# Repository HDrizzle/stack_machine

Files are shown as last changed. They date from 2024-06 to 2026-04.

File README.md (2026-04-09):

# Stack Machine Version 2

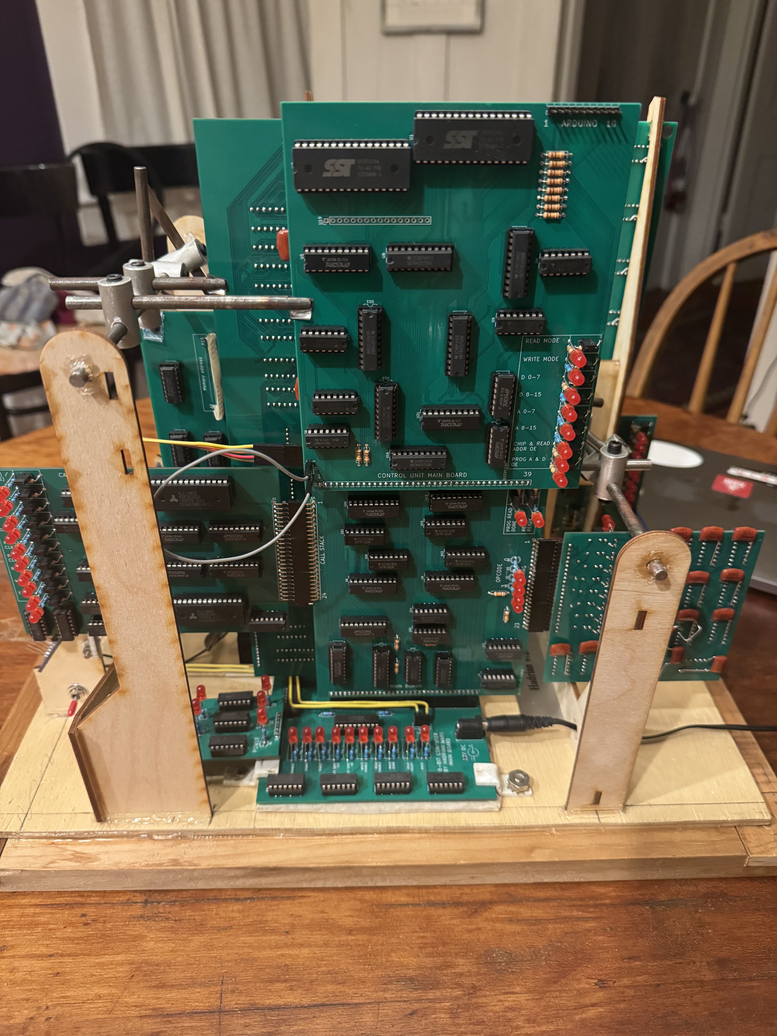
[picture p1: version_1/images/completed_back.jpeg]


Photo of Version 1

## Changes from previous version

* The timing will be completely redone: A single normal clock signal, not the stupid "AB Alternating" I made up for the original.
* The PC will be incremented and a new instruction fetched during any non-flow-control instructions except when the GPRAM is used and the PC is in the same RAM chip (the RAM chips have 15 address lines each) as whatever is being accessed. The bus timing will also be very flexible and will be faster when possible but still slow when the memory is being accessed twice for example.
* Bus read/write addresses are both now 5 bits. The WRITE/MOVE instruction formats will remain the same and the extra bit (MSB to be exact) will be set based on duplicate opcodes for WRITE/MOVE that are otherwise interpreted the same. 1 extra WRITE opcode and 3 extra MOVE opcodes.
* The opcode decoder is actually 3 bits. There will be 4 bits used for extra MOVE/WRITE instructions (see above).
* Interrupts: There will be seperate interrupt GOTO latches that go to a dedicated interrupt handler function. That function should save the state of everything else (including the regular GOTO latches, which is why interrupt GOTO latches are seperate) onto the stack then do whatever depending on the interrupt code.
* GOTO latches can be written to the bus (see above). The goto decider doesn't need to be because it's simple to get its value from an IF-ELSE.
* The control unit will be able to fetch instructions from the GPRAM: Program addresses starting at 2^15 (32,768, halfway through the old flash memory space) will load 2 consecutive bytes (an instruction is 2 bytes) from the GPRAM. The GPRAM address of the first byte (lower byte of the instruction) will be determined by: `(prog_addr - 32,768) * 2`. Since that will only happen at or above 32,768 then the MSB will not be used in the math and will be used to determine whether to read from flash or GPRAM.
* Flash program space is selectable: The flash chips have 17 address lines, while 15 are used (see above about half the program address space being mapped to the GPRAM). This means that the top 2 lines can be connected to jumpers to select between 4 different programs.
* Flash program can be written to from the bus: The programming interface takes 8 data inputs + power and GND. The old interface to plug an Aduino in to program it will still be there of course but it can be selected by a jumper to be either the external pins (to Arduino) or from the bus.
* The stack is 32k instead of 64k so only one memory chip is used, although 32k is still incredibly excessive.

### GPRAM Parallelization

The RAM chips have 15 address lines each so there will be two of them (Lower and Upper Domains). This means that they can be used seperately at the same time, for example fetching the new instruction (If the PC is in the RAM) and also doing GPRAM read/write, as long as these operations are using seperate domains.
Memory users will use either (or both) of the lower or upper RAM domains:

* Program: PC and data read into instruction registers A & B
* Heap R/W: Exactly the same as the original

# Program instructions

Each instruction will be 16 bits and interpreted by the control unit. The first 3 bits (0 - 3) of the instruction will address the below list of operations. The rest of the instruction (bits 4 - 15) may be ignored or used for different things depending on the specific operation.

Here's the current list of the operation codes (opcodes):

0. `MOVE` - Bus usage - The rest of the instruction will be interpreted as follows: bits 8 - 11 address the device which will set the state of the bus (TX) and bits 12 - 15 will address the device to read from it (RX). Bits 4 - 7 are sent to the ALU as it's opcode incase the data is comming from it.
1. `WRITE` - Writes instruction bits 4 - 11 to the bus. Bits 12 - 15 address the device to read from it.
2. `GOTO` - Saves the 2 execution pointer GOTO latches (each of them are 1 byte) to the program counter
3. `GOTO-IF` - Reads the LSB of the value in the goto decider latch and does a GOTO only if it is 1, otherwise does nothing
4. `HALT` - Stops the clock, usefull for debugging
5. `CALL` - Effectively the same as `GOTO` but also pushes the return address (current value of program counter) onto the call stack. Note: The return address can be copied as-is and does not need to be incremented because it will be incremented normally after each `RETURN` instruction when it is used. If bit 4 is 1 this means that this call is calling the interrupt handler using the Interrupt GOTO latches.
6. `RETURN` - The program counter will be set to the return address popped off the top of the call stack. If bit 4 is 1 this means that this return instruction is returning from the interrupt handler function and will allow interrupts again.
7. `CONFIG-INT` - Configure interrupt. Bit 4 enables or disables interrupts. Interrupts are disabled on startup.

The following are treated as either MOVE or WRITE by the sequencer and set the bus TX and RX MSBs. The original MOVE and WRITE have all MSBs = 0.

8. `MOVE` - MSBs TX=1, RX=0
9. `MOVE` - MSBs TX=0, RX=1
10. `MOVE` - MSBs TX=1, RX=1
11. `WRITE` - MSBs RX=1

# Bus

Up to 15 devices can read the bus and 16 write to it.
Devices that can read the bus (RX):

0. `NONE` - Nothing reads this so that bytes can be popped from the stack without them going anywhere.
1. `STACK-PUSH` - Stack controller (Push)
2. `ALU-A` - ALU latch A
3. `ALU-B` - ALU latch B
4. `GOTO-A` - Control unit - Program counter GOTO latch A (first byte)
5. `GOTO-B` - Control unit - Program counter GOTO latch B (second byte)
6. `GOTO-DECIDER` - Control unit - GOTO decider latch (For GOTO-IF)
7. `GPRAM` - GPRAM - Write
8. `GPRAM-INC-ADDR` - GPRAM - Write (++ address)
9. `GPRAM-ADDR-A` - GPRAM - Address bits 0 - 7
10. `GPRAM-ADDR-B` - GPRAM - Address bits 8 - 15
11. `GPIO-WRITE-A` - Writes to GPIO output pins 0 - 7
12. `OFFSET-WRITE` - Replaces value in stack at `ToS - offset`
13. `SET-STACK-OFFSET` - Sets the stack offset byte
14. `ALU-C-IN` - ALU latch for carry and borrow, only LSB is used. Make sure this is always zero when not being used otherwise additions will be wrong.
15. `GPIO-WRITE-B` - Writes to GPIO output pins 8 - 15
16. `INT-GOTO-A` - Interrupt GOTO A
17. `INT-GOTO-B` - Interrupt GOTO B
18. `VECTORS-A` - Vector graphics A input
19. `VECTORS-B` - Vector graphics B input
20. `VECTORS-C` - Vector graphics C input
21. `VECTORS-D` - Vector graphics D input
22. `INT-AND-MAIN-TIMER-ADDRESS` - Bits 0 - 1 address 1 of the 4 interrupt timers. Bit 2 will reset the addressed counter to 0.
23. `INT-TIMER-CONFIG-MAX` - Sets the start value of one of the interrupt timers
24. `INT-TIMER-CONFIG-TIMEBASE-AND-ENABLE` - Configures one of the interrupt timers, see `timer_board.md`
25. `FLASH` - Flash programming interface, same as the arduino connection
26. `RX-26` - Expansion RX 25

...

31. `RX-31` - Expansion RX 31

Devices that can write to the bus (TX):

0. `STACK-POP` - Stack controller (pop)
1. `OFFSET-READ` - Reads value from stack at `ToS - offset`, does not affect the ToS
2. `ALU` - ALU output
3. Control unit instruction bits 4 - 11, used for the `WRITE` instruction
4. `GPRAM` - GPRAM - Read
5. `GPRAM-INC-ADDR` - GPRAM - Read (++ address)
6. `GPRAM-ADDR-A` - GPRAM - Address bits 0 - 7
7. `GPRAM-ADDR-B` - GPRAM - Address bits 8 - 15
8. `GPIO-READ-A` - Reads GPIO input pins 0 - 7
9. `MAIN-TIMER` - 8 bits of the main timer, addressed by `INT-AND-MAIN-TIMER-ADDRESS`
10. `INT-TIMER` - Current value of 1 of the 4 interrupt timers, addressed by `INT-AND-MAIN-TIMER-ADDRESS`
11. `GPIO-READ-B` - Reads GPIO input pins 8 - 15
12. `INT-CODE` - Most recent interrupt code, will be cleared upon read
13. `INT-COUNT` - Number of interrupts in queue, will overflow past 255
14. `GET-STACK-OFFSET` - Retrieves stack offset, needed to save state during interrupt
15. `GET-GOTO-A` - Read GOTO Latch A
16. `GET-GOTO-B` - Read GOTO Latch B
17. `TX-17` - Expansion TX 17

...

31. `TX-31` - Expansion TX 31

# The Stack

The stack will simply be a piece of memory seperate from the pGPRAM and managed by hardware, its has 32k x 8-bit words.

There will be two ways to access the stack:

1. Push and Pop
2. Using the current ToS pointer - stack offset (`OFFSET-WRITE` and `OFFSET-READ`) (does not change ToS). The stack offset will be a 1-byte number set from the bus (`SET-STACK-OFFSET`) and will not affect pushes and pops.

# ALU

The ALU uses 2 8-bit latches for input and has 1 output. The specific operation it does is controlled by 4 bits (2^4 = 16 operations). All operations that result in a boolean output all `0`s except for the result which is the LSB.

0. `ADD` - Add
1. `ADD-C` - Addition carry output (just the LSB will be set), this can be written directly into `ALU-C-IN`
2. `NOT` - Bitwise NOT (latch A)
3. `OR` - Bitwise OR
4. `AND` - Bitwise AND
5. `XNOR` - Bitwise XNOR, whether each pair of bits are equal
6. `SHIFT` - Bitshifts A left by the first 3 bits of B, bits that go off the end DO wrap around.
7. `EQ` - Whether bytes are equal
8. `A` - Contents of A latch
9. `B` - Contents of B latch
10. `EXT-10` - Extension (not implemented)
11. `EXT-11` - Extension (not implemented)
12. `EXT-12` - Extension (not implemented)
13. `EXT-13` - Extension (not implemented)
14. `EXT-14` - Extension (not implemented)
15. `EXT-15` - Extension (not implemented)

# Flow Control

There are four instructions for flow control: `GOTO`, `GOTO-IF`, `CALL`, and `RETURN`.

## GOTO and GOTO-IF

A `GOTO` instruction is used to jump to anywhere in the program. it uses the two 8-bit latches (`GOTO-A` and `GOTO-B`) to set the 16-bit program counter. Due to how the hardware is set up, the PC will be incremented after each goto instruction. This means that the previous address to where the execution should jump to must be used.

`GOTO-IF` is a conditional goto which will do what is described above only if the bit set by `GOTO-DECIDER` from the LSB of the bus is 1, otherwise it does nothing. This is the only instruction that allows the computer to "branch" or "make decisions".

There are macros, `@goto(anchor_name)` and `@goto_if(anchor_name)` that make GOTOs a lot easier.

## Functions and the call stack

Functions in the machine code are defined by `CALL` and `RETURN` instructions. To call a function, make sure the correct pointer to the beginning of the function is stored in the control unit goto A and B latches. Then use the `CALL` instruction which is basically a GOTO but will first put the current program counter value onto the call stack as the return address. The return instruction pops a return address off of the call stack and continues execution.

There is a macro in the assembly language, `@call(function_name)` that makes calling a lot easier.

The call stack is a seperate stack memory containing 256 (1 byte address size) 16-bit words. Each word will be a return address - where to set the program counter during a `RETURN` instruction.

# I/O

There are 16 input and 16 seperate output pins accessible with the `GPIO-READ-A`, `-B` and `GPIO-WRITE-A`, `-B` bus sources/destinations.

## Writing to the display

The display has 32 x 32 LEDs, any given row of 8 pixels are written all at once with one byte. These rows of 8 are addressed by a 7-bit number starting at the top-left and going across for 4 per row (32 / 8 = 4) for each of the 32 rows of the display. The display currently is attached to the gpio-write a and b outputs with gpio-write-a being the address (MSB is ignored) and gpio-write-b being the data. The signal to write the address/data to the display's memory is sent by the hardware when gpio-write-b is written to, meaning the address should be written first and then the data.

# General purpose static-RAM (GPRAM)

This piece of memory does not have any hardware protection like the stack and can be writen to and read from at any location. It will have a 16-bit address by 8-bit word size (65,536 bytes) just like the stack.

Its address can be optionally incremented upon reads/writes and can be directly set from the bus (`GPRAM-ADDR-A` and `GPRAM-ADDR-B`). For the instructions where the address is incremented, that will happen after the read/write.

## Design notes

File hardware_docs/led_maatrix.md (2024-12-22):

# 32 x 32 LED matrix display

Each LED is either on or off

To write to display: Set the 16 bit input so that the first 8 bits address a "byte" of "data" to write to on the display.
Specifically, the bits 0 - 1 address the column and bits 2 - 6 address the row. Bit 7 does nothing.

Each column is 8 bits/pixels wide and is set on a row all at once with bits 8 - 15.

## Memory

2x 32k x 8 SRAM chips in parallel for 32k 16-bit words.
Usage (read): 64 x 16
Usage (write): 128 x 8

## Display loop

For each iteration, 1024/16 = 64 words will be accessed. Each of the 8 drivers will use 1 word per row activation.

### For each row activation (0 - 7)

Every bit in each 16-bit word should be used during the same multiplex iteration.
For each LED driver: Load in the 16-bit word located at address `(floor(driver / 2) * 16) + (driver % 2) + (2 * row_activation)`, this can be implemented easily by concatenating the bits of each term together.
Set the row source from previous row to this one.

## LED drivers

1024 x 20 mA per LED is 20 A (a bit more then 1 A per driver), at 5 volts thats 100 W!! (new screen metric just dropped: 0.1 W/pixel)
Going to use high-side N-channel enhancement MOSFET switches. Update: using the IRF9540.

## Timing

The logic will represent a for loop like so:
```
for row_activation in 0..8 {
	for driver in 0..8 {
		Set memory address
		Get 16-bit word
		for bit_address in 0..16 {
			Clock bit into driver
		}
		Update driver latch
		Load latest written address/data into memory (this isn't necessary but is simpler then having another piece of logic that unly updates on input update)
	}
}
```

Since each variable iterates over a power of two, all 3 counters will just loop over. There is no need to explicitely reset them because that will happen on startup. The bit address counter is driven by the main clock anded with the `Bit address counter enable` signal.

LED driver uptating, representing the pseudo-code inside the `for driver in 0..8` for-loop.
NOTE: The clock pulse that brings the counter from 15 to 0 will be really small since it will be disabled when the counter overflows, although this cannot be represented with the diming diagram, it won't be a race condition.
```
{
  signal: [
    {name: "CLK", wave: "p|.......|"},
    {},
    {name: "Memory read", wave: "l|..h.l..|"},
    {name: "Memory output latch CLK", wave: "l|...hl..|"},
    {name: "Bit address", wave: "2222..2222", data: ["13", "14", "15", "0", "1", "2", "3", "4"]},
    {name: "Counter enable", wave: "h|.l..h..|"},
    {name: "Counter CLK", wave: "p|..l.p..|"},
    {name: "Driver CLK enable", wave: "h|.l.nh..|"},
    {name: "Driver CLK", wave: "n|.l.nn..|"},
    {name: "Driver LE", wave: "l|.hl....|"},
    {},
    {name: "Memory write set data", wave: "l|....h.l|"},
    {name: "Memory write", wave: "l|.....pl|"},
  ]
}
```
I made sure there is a time gap between when the counter rolls over and when `Momery read` goes high because I don't know whether the memory read is edge or level triggered.

The `Memory write set data` signal will control some further combinational logic as follows:
* Low: the read address transparent latch is enabled
* High: The data input address latch is enabled, one of the data input data latches is enabled depending on the LSB of the address.

The `Memory write` should only write to one of the memory chips based on the LSB of the data address, just like the two data latches.

https://pdftobrainrot.org/share/072650e9ef6a43f492dbb5a2f9bec8e8

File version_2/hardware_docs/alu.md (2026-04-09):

# Arithemtic & Logic Unit (ALU)

The ALU will have 3 inputs from the bus:

2. `ALU-A` - ALU latch A
3. `ALU-B` - ALU latch B
14. `ALU-C-IN` - ALU latch for carry and borrow, only LSB is used.

And one output:

2. `ALU` - ALU output

The operation that is performed is controlled through a 4-bit address connected directly from bits 4-7 of the current instruction on the control unit main board.

## Expansion connector

Since only 10 of the 16 addressable instructions are implemented, there is an expansion connector on the ALU board which will allow modding with up to 6 custom functions.

For flexible timing support for the extension, the extension's `TX Ready` and `RX Extend half cycle (to controller)` signals are connected to the corresponding actual bus outputs.

The connections are (1-indexed because pin numbers):

1. A operand 0

...

8. A operand 7
9. B operand 0

...

16. B operand 7
17. C In (1 bit only)
18. Select# 10

...

23. Select# 15
24. Output 0

...

31. Output 7
32. TX Ready, set on rising edge just like actual bus signal
33. A updated, set for 1 cycle on rising edge after input latch clocked on falling edge
34. B updated, set for 1 cycle on rising edge after input latch clocked on falling edge
35. C updated, set for 1 cycle on rising edge after input latch clocked on falling edge
36. CLK
37. RX Extend half cycle, same timing as bus
38. +5V
39. GND

## Timing

There will be 2 main TX timing sequences based on whether the opcode is addressing a built-in function or external function.

### Built-in function TX

`TX Ready` will alway go high immediately since all built-ins are completely combinational. EX Extend (from controller) will be used as per usual to extend the OE to the bus another half cycle.

## External function TX

The function-select# lines will work different, this time not staying low for the `RX Extend` bus input. The `TX Ready` signal to the bus will only go high when the extension's `TX Ready` output goes high. The extension is responsible for extending its OE when the bus `RX Extend (from controller)` goes high.

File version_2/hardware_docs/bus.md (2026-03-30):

# Bus controller

TX and RX addresses are both 5 bits. Both the TX and RX devices have the option to delay TX or RX respectively.

Bus TX ready signals will only last 1 cycle so that recieving logic doesn't have to deal with race conditions.

If the signal `RX extend half cycle` is high then values on the bus should remain valid for another half cycle after "TX Ready" goes low. This is to allow memory writes to happen without sketchy edge cases. This signal is in place to optimize the best possible bus move timing (1 clock cycle, not counting instruction load) but still allow memory writes to happen cleanly. The `RX extend half cycle (to TX device)` signal is delayed by a half cycle to make the timing logic in TX devices simpler.

There may be glitches in the initial move TX signal to bus devices so those signals should always be clocked in to logic on the -edge before anything is done.

When the same device is TXing and also RXing, that device will be responsible for possibly delaying the RX timing chain for 2 clock cycles.

Timing signals
| Signal | Set by | Set clock edge |
| - | - | - |
| Move / TX | Main sequencer | + |
| TX Ready | TX Device | + |
| RX Not Ready | RX Device | + |
| RX extend half cycle (to controller) | RX Device | + |
| RX extend half cycle (to TX device) | controller | - |
| Bus save CLK | Bus controller | - |
| Bus save OE | Bus controller | + |
| Move done | Bus controller | - (half cycle) |

## LEDs

There will be a normal sequencer debug interface on the main board (not sequencer board). There will also be LEDs for each of: Fault, RX Extend to controller, RX not ready, TX ready for each slot. These LEDs will also function as pulldown resistors in the case of empty slots.

## Timing

Plot sources to be pasted into <a href="wavedrom.com/editor.html">Wavedrom</a>.

The data source and destination will have their own sequences

### Without RX extend half cycle

Fastest possible case
```
{
  signal: [
    {name: "CLK", wave: "lhlh"},
	{},
	{name: "Main sequencer -> Move", wave: "lh.l"},
	{},
    {name: "Bus TX", wave: "lh.l"},
	{name: "TX ready", wave: "lh.l"},
	{name: "(actual data valid)", wave: "lh.l"},
	{name: "RX not ready", wave: "l..."},
	{name: "RX extend half cycle (to controller)", wave: "l..."},
	{name: "RX extend half cycle (to TX device)", wave: "l..."},
	{name: "Bus save CLK", wave: "l..."},
	{name: "Bus save OE", wave: "l..."},
	{name: "Move done", wave: "l.hl"}
  ],
  edge: []
}
```

TX not ready, RX Ready
```
{
  signal: [
    {name: "CLK", wave: "lhlhlh"},
	{},
	{name: "Main sequencer -> Move", wave: "lh.l.."},
	{},
    {name: "Bus TX", wave: "lh.l..", node: ".a"},
	{name: "TX ready", wave: "l..h.l", node: "...b"},
	{name: "(actual data valid)", wave: "l..h.l"},
	{name: "RX not ready", wave: "l....."},
	{name: "RX extend half cycle (to controller)", wave: "l....."},
	{name: "RX extend half cycle (to TX device)", wave: "l....."},
	{name: "Bus save CLK", wave: "l....."},
	{name: "Bus save OE", wave: "l....."},
	{name: "Move done", wave: "l...hl"}
  ],
  edge: ["a~>b TX Delay (possibly instant)"]
}
```

TX not ready, RX Not ready
```
{
  signal: [
    {name: "CLK", wave: "lhlhlhlh"},
	{},
	{name: "Main sequencer -> Move", wave: "lh.l...."},
    {},
	{name: "Bus TX", wave: "lh.l....", node: ".a"},
	{name: "TX ready", wave: "l..h.l..", node: "...b"},
	{name: "(actual data valid)", wave: "l..h.h.l"},
	{name: "RX not ready", wave: "l..h.l.."},
	{name: "RX extend half cycle (to controller)", wave: "l......."},
	{name: "RX extend half cycle (to TX device)", wave: "l......."},
	{name: "Bus save CLK", wave: "l...h.l."},
	{name: "Bus save OE", wave: "l....h.l"},
	{name: "Move done", wave: "l.....hl"}
  ],
  edge: ["a~>b TX Delay (possibly instant)"]
}
```

### With RX extend half cycle

Fastest possible case
```
{
  signal: [
    {name: "CLK", wave: "lhlhl"},
	{},
	{name: "Main sequencer -> Move", wave: "lh.l."},
	{},
    {name: "Bus TX", wave: "lh.l."},
	{name: "TX ready", wave: "lh.l."},
	{name: "(actual data valid)", wave: "lh..l"},
	{name: "RX not ready", wave: "l...."},
	{name: "RX extend half cycle (to controller)", wave: "lh.l."},
	{name: "RX extend half cycle (to TX device)", wave: "l.h.l"},
	{name: "Bus save CLK", wave: "l...."},
	{name: "Bus save OE", wave: "l...."},
	{name: "Move done", wave: "l...h"}
  ],
  edge: []
}
```

TX not ready, RX Ready
```
{
  signal: [
    {name: "CLK", wave: "lhlhlhl"},
	{},
	{name: "Main sequencer -> Move", wave: "lh.l..."},
	{},
    {name: "Bus TX", wave: "lh.l...", node: ".a"},
	{name: "TX ready", wave: "l..h.l.", node: "...b"},
	{name: "(actual data valid)", wave: "l..h..l"},
	{name: "RX not ready", wave: "l......"},
	{name: "RX extend half cycle (to controller)", wave: "l..h.l."},
	{name: "RX extend half cycle (to TX device)", wave: "l...h.l"},
	{name: "Bus save CLK", wave: "l......"},
	{name: "Bus save OE", wave: "l......"},
	{name: "Move done", wave: "l.....h"}
  ],
  edge: ["a~>b TX Delay (possibly instant)"]
}
```

TX not ready, RX Not ready
```
{
  signal: [
    {name: "CLK", wave: "lhlhlhlhlh"},
	{},
	{name: "Main sequencer -> Move", wave: "lh.l......"},
    {},
	{name: "Bus TX", wave: "lh.l......", node: ".a"},
	{name: "TX ready", wave: "l..h.l....", node: "...b"},
	{name: "(actual data valid)", wave: "l..h.h...l"},
	{name: "RX not ready", wave: "l..h.l...."},
	{name: "RX extend half cycle (to controller)", wave: "l....h.l.."},
	{name: "RX extend half cycle (to TX device)", wave: "l.....h.l."},
	{name: "Bus save CLK", wave: "l...h...l."},
	{name: "Bus save OE", wave: "l....h...l"},
	{name: "Move done", wave: "l.......hl"}
  ],
  edge: ["a~>b TX Delay (possibly instant)"]
}
```

## List of bus slots

0. Control unit main board
1. Program memory
2. GPRAM Shared memory
3. GPRAM Sequencer & address
4. ALU
5. Stack data/main
6. Interrupt handler data/main
7. Timers
8. Vector digital board
9. I/O Controller (horizontal, to the side)
10. Expansion slot 0
11. Expansion slot 1
12. Expansion slot 2
13. Expansion slot 3, mechanical supports in place to attach LED display from version 1

## TX/RX addresses to physical slots TODO

| Bus slot | TX 0 | TX 1 | TX 2 | TX 3 | RX 0 | RX 1 | RX 2 | RX 3 |
| - | - | - | - | - | - | - | - | - |
| Control unit main board | 3 | 15 | 16 | NA | 4 | 5 | 16 | 17 (5th RX, 6, is GOTO decider) |
| Program memory | NA | NA | NA | NA | 25 | NA | NA | NA |
| GPRAM Shared memory | NA | NA | NA | NA | NA | NA | NA | NA |
| GPRAM Sequencer & address | 4 | 5 | 6 | 7 | 7 | 8 | 9 | 10 |
| ALU | 2 | NA | NA | NA | 2 | 3 | 14 | NA |
| Stack data/main | 0 | 1 | 14 | NA | 1 | 12 | 13 | NA |
| Interrupt handler data/main | 12 | 13 | NA | NA | NA | NA | NA | NA |
| Timers | 9 | 10 | NA | NA | 22 | 23 | 24 | NA |
| Vector digital board | NA | NA | NA | NA | 18 | 19 | 20 | 21 |
| I/O Controller | 8 | 11 | NA | NA | 11 | 15 | NA | NA |

## Expansion slot jumper configuration

There are 4 expansion slots, each with 4 TX and 4 RX connections.

Extra TX addresses: 15, extra RX addresses: 6

TX: 16 x 15, RX: 16 x 6

On tthe bus board there are 2 pairs of 0.1" male pin headers to place jumper cables to connect the expansion slots

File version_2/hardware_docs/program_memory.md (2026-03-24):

# Program memory board

The program emory consists of 2 128k x 8 flash chips in parallel for 16 bit word size. Since the control unit can only address 2^15 flash memory words and there are 2^17 available, there will be 2 jumpers that configure the 2 highest MSBs of both the chips.

## Writing

Just like on Version 1 there will be a 10-pin header to connect an Arduino (or any microcontroller) for programming. There will also be a bus connection (`FLASH`) to set the state of the 8 data input pins. There will be a jumper to select between the external (Arduino) and the Bus programming interfaces.

## Logic (all combinational)

Inputs:

* External/Bus `Write mode enable` input
* Write interface `WE#`
* `Bus -> Write` Jumper
* Instruction read source (0=flash)

Outputs:

* `Read mode` = (!`Write mode`) & (!Read source)
* `Write mode` = `Write mode enable`
* `Chip & read addr OE` = `Read mode`
* `Prog A & D OE` = `Write mode`
* `Write interface select (0=bus, 1=external)` = (External `Write mode enable` input) & !((Bus `Write mode enable` input) & (`Bus -> Write` Jumper))

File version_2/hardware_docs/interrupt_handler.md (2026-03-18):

# Hardware Interrupt Handler

This will be a generic board connected to the bus. Interrupts will be triggered by rising edges, falling edges, timers, and comparators. They can be queued up to as many as 256. Both of the read and write pointers will be incremented AFTER the read/write. When an interrupt is triggered or when the handler returns and there is another one queued up, the normal program instruction will be overridden and the special `CALL` will be run with bit 4 set to 1.

Every interrupt has an 8-bit "code". The first 3 bits address the source of the interrupt, bit 3 is always 0, the last 4 bits vary depending on what the interrupt is. Interrupt sources are as follows:

0. Interrupt timer 0
1. Interrupt timer 1
2. Interrupt timer 2
3. Interrupt timer 3
4. Configurable, +4 bits
5. Configurable, +4 bits
6. Configurable, +4 bits
7. Configurable, +4 bits

The 4 configurable interrupts each correspond to a 5-pin header with the 1st pin being the active-high interrupt signal and the other 4 being the upper 4 bits of the interrupt code. For example 16 buttons could be encoded into the 4 customizable bits with the interrupt pin being triggered by any of them.

## Minimum pulse width (CAUTION)

Usually an extremely short pulse (shorter than 1 clock cycle) will be detected as an interrupt since there are SR latches used, however there is a 1/16 chance of that pulse occuring between when that interrupt is read and when it is reset meaning it will be missed. To gurantee the interrupt is never missed make sure it is longer than 1 clock cycle.

## Edge detection

There will be 8 SR latches to remember the state of an interrupt from the previous sample so if an interrupt input goes high for multiple samples there will only be 1 interrupt triggered at the beginning.

## Interface w/ control unit

There will be a single signal to the control unit timing, `Interrupt` which is read on the +clock edge. It will remain high as long as there is at least 1 interrupt in the queue.

## To bus (TX)

12. `INT-CODE` - Oldest interrupt code, will be cleared upon read
13. `INT-COUNT` - 0 to 255, how many interrupts are in the queue

## Timing

Plot sources to be pasted into <a href="wavedrom.com/editor.html">Wavedrom</a>.

Main sequence (independent of computer's sequence)

Pseudocode

```
Loop:
	CLK interrupt address
	CLK current state
	If current state && !prev state:
		CLK write memory counter, Set memory source to write
		Memory write
		Set memory source to read, Current state reset
	Set prev state
	CLK INT-CODE Pre-latch// This must be on -edge to not coincide with the post-latch CLK from bus read
```

Timing diagram (no interrupt)

```
{
	signal: [
		{name: "CLK", wave: "lhlhlhl"},
	{},
		{name: "Interrupt address CLK", wave: "lh.l.h.", node: ".....b"},
		{name: "Current state CLK", wave: "l.h.l.h"},
		{name: "Current state", wave: "l......"},
		{name: "Prev state", wave: "l......"},
		{name: "Memory source (0=read, 1=write)", wave: "l......"},
		{name: "Write address++", wave: "l......"},
		{name: "Memory write", wave: "l......"},
		{name: "Current state reset", wave: "l..hl.."},
		{name: "INT-CODE Pre-latch CLK & Prev state set", wave: "l...hl.", node: "....a"},
	],
	edge: ["a~>b Begin cycle"]
}
```

Timing diagram (Interrupt)

```
{
	signal: [
		{name: "CLK", wave: "lhlhlhlhl"},
	{},
	{name: "Interrupt address CLK", wave: "lh.l...h.", node: ".......b"},
		{name: "Current state CLK", wave: "l.h.l...h", node: "..c"},
		{name: "Current state", wave: "l.h......"},
		{name: "Prev state", wave: "l.....h.."},
		{name: "Memory source (0=read, 1=write)", wave: "l.h..l..."},
		{name: "Write address++", wave: "l.....hl."},
		{name: "Memory write", wave: "l..hl...."},
		{name: "Current state reset", wave: "l..hl....", node: "....d"},
		{name: "INT-CODE Pre-latch CLK & Prev state set", wave: "l.....hl.", node: "......a"},
	],
	edge: ["a~>b Begin cycle", "c~>d Short interrupt will be missed"]
}
```

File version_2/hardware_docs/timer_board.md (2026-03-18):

# Timer board

The timing board will have its own crystal and a large clock divider, it can also triger interrupts.

The base clock will be a 1 MHz crystal. That clock will be fed into 3 cascaded 12-bit counters which roll over every 68719.476736 seconds.

## Interrupt timers (x4)

Interrupt timers will be 8-bit counters with a configurable max value and time base. When they count past their max value and rollover they may be configured to cause an interrupt. Setting the max value to n will make it rollover at n+1, so setting it to 255 will cause it to rollover normally, TODO: Make sure this is how the simulation works.

The timer reset logic resets the timer immediately when it reaches max+1, so the comparator output is high very briefly. To ensure that the interrupt pulse is not too short for the interrupt handler (see "minimum pulse width" in its readme) it must be extended to greater than 1 clock cycle.

## From bus (RX)

22. `INT-AND-MAIN-TIMER-ADDRESS` - Bits 0 - 1 address 1 of the 4 interrupt timers OR a byte of the main timer. Bit 2 will reset the addressed interrupt timer to 0.
23. `INT-TIMER-CONFIG-MAX` - Sets the max value (will rollover past this, not at it)
24. `INT-TIMER-CONFIG-TIMEBASE-AND-ENABLE` - Bits 0 - 3 address every even-indexed bit of the main 36-bit divider up to bit 30, so 0x0 -> 1 MHz, 0x1 -> 250 KHz and so on. Bit 4 sets whether the timer is allowed to cause interrupts. Bit 5 sets whether the counter is currently counting. Bit 0 in this case is the actual 1 MHz signal.

## To bus (TX)

9. `MAIN-TIMER` - 8-bit section of the 36 bit main timer. Addressed by the `INT-AND-MAIN-TIMER-ADDRESS` (see above). Bits indexed are as follows based on that address: 0 -> 4-11, 1 -> 12-19, 2 -> 20-27, 3 -> 28-35. Bit 0 is actually 500 KHz because its still divided by 2.
10. `INT-TIMER` - reads the current value of any of the 4 interrupt timers, addressing works the same as `MAIN-TIMER` and is controlled by `INT-AND-MAIN-TIMER-ADDRESS`.

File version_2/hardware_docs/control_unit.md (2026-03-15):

# Control unit

https://lucid.app/lucidchart/32ad8e9d-d2d1-47b0-a4b6-105ece57e4e0/edit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

Plot sources to be pasted into <a href="wavedrom.com/editor.html">Wavedrom</a>.

## Startup

1. Started by the `Set` input from the startup controller going high, the sequencer `Start` input will go high for exactly 1 cycle (update on -edge). `Start` will disable the GOTO latches OE, post-adder latch OE, and the call stack OE. Pullup resistors will set the inputs to the pre-adder latch to 0xFFFF so when it is incremented it starts at instruction 0x0000.
2. Clock pre-adder address latch
3. Clock post-adder address latch
3. Begin regular cycle

```
{
  signal: [
	{name: "CLK", wave: "lhlhlh"},
	{},
    {name: "Enable", wave: "lh...."},
    {name: "Start", wave: "l.h.l."},
	{name: "Pre-adder latch CLK", wave: "l.h.l."},
    {name: "Load Instruction", wave: "l..h.l"}
  ],
	edge: ["a~>b Wait for instruction done"]
}
```

## Cycle, PC incrementation may be done in parallel

There will be an SR latch `Instruction done` which will be read on +edge to continue with `Begin instruction sequence` for the next instruction.

Load from FLash
```
{
  signal: [
	{name: "CLK", wave: "lhlhlhl"},
	{},
    {name: "Load Instruction", wave: "lh.l..."},
	{name: "Post-adder latch CLK & OE", wave: "lh.l..."},
	{name: "Flash read (PC MSB=0)", wave: "lh.l..."},
    {name: "Instruction pre-latches CLK", wave: "l.h.l..", node: "..a"},
	{name: "Instruction post-latch CLK", wave: "l..h.l.", node: "...b"},
	{name: "Begin instruction sequence", wave: "l..h.l."},
    {name: "Instruction done", wave: "l.hl2..", data: ["flow-ctrl"]}
  ],
	edge: ["a~>b Wait for instruction done"]
}
```

The `Instruction load possible` signal is combinational from the GPRAM sharing circuit and the PC MSB. If the PC MSB = 0 then it is always 1, otherwise it depends on the PC MSB, the GPRAM MSB, and whether the GPRAM is being used.

If at any time during an instruction load, the `Instruction load possible` signal goes low (only will happen from GPRAM usage, always +edge), then the timing chain must loop back into the waiting loop (`Load Instruction`) for it to go high again.

Load from RAM (non delayed)
```
{
  signal: [
	{name: "CLK", wave: "lhlhlhlh"},
	{},
    {name: "Load Instruction", wave: "lh.l...."},
	{name: "Post-adder latch CLK & OE", wave: "lh...l.."},
	{name: "RAM read (PC MSB=1)", wave: "lh...l.."},
    {name: "Instruction load possible (read on -edge)", wave: "xh......"},
	{name: "RAM LSB", wave: "l..h.l.."},
	{name: "Instruction pre-latch A CLK", wave: "l.h.l..."},
	{name: "Instruction pre-latch B CLK", wave: "l...h.l.", node: "....a"},
	{name: "Instruction post-latch CLK", wave: "l....h.l", node: ".....b"},
	{name: "Begin instruction sequence", wave: "l....h.l"},
    {name: "Instruction done", wave: "l...hl2.", data: ["flow-ctrl"]}
  ],
	edge: ["a~>b Wait for instruction done"]
}
```

Load from RAM, start delayed
```
{
  signal: [
	{name: "CLK", wave: "lhlhlhlhlh"},
	{},
    {name: "Load Instruction", wave: "lh.l......"},
	{name: "Post-adder latch CLK & OE", wave: "lh.....l.."},
	{name: "RAM read (PC MSB=1)", wave: "lh.....l.."},
    {name: "Instruction load possible (read on -edge)", wave: "l..h......"},
	{name: "RAM LSB", wave: "l....h.l.."},
	{name: "Instruction pre-latch A CLK", wave: "l...h.l..."},
	{name: "Instruction pre-latch B CLK", wave: "l.....h.l.", node: "......a"},
	{name: "Instruction post-latch CLK", wave: "l......h.l", node: ".......b"},
	{name: "Begin instruction sequence", wave: "l......h.l"},
    {name: "Instruction done", wave: "l.....hl2.", data: ["flow-ctrl"]}
  ],
	edge: ["a~>b Wait for instruction done"]
}
```

## Interrupts

The signal `Interrupt` from the interrupt handler is read on the positive edge and used to determine whether `Instruction post-latch OE` is set. The instruction data bus has pull up/down resistors to hardcode the default value to the interrupt call instruction (0x0015) so when the `Instruction post-latch OE` is low then the interrupt handler will be called.

The interrupt call can only happen when `Interrupt in-progress` is low and `Interrupt enabled` is high. `Interrupt enabled` is an SR latch which is set by:

 * The `CALL` (disable) and `RETURN` (enable) instructions if bit 4 is high (interrupts are automatically disabled when in the interrupt handler or any function calls within it)
 * Disabled on startup
 * The `CONFIG-INT` instruction will enable or disable interrupts. This should not be used inside the interrupt handler except in some kind of weird use case I can't think of.

```
{
  signal: [
	{name: "CLK", wave: "lhlhlhl"},
	{},
    {name: "Load Instruction", wave: "lh.l..."},
	{name: "Post-adder latch CLK & OE", wave: "lh.l..."},
	{name: "Flash read (PC MSB=0)", wave: "lh.l..."},
    {name: "Instruction pre-latches CLK", wave: "l.h.l..", node: "..a"},
	{name: "Instruction post-latch CLK", wave: "l..h.l.", node: "...b"},
	{name: "Instruction post-latch OE", wave: "h..l.h."},
	{name: "Interrupt (latched on +edge)", wave: "x.h...."},
	{name: "Interrupt in-progress", wave: "l...h.."},
	{name: "Begin instruction sequence", wave: "l..h.l."},
    {name: "Instruction done", wave: "l.hl2..", data: ["flow-ctrl"]}
  ],
	edge: ["a~>b Wait for instruction done"]
}
```

## Non-control-flow parallel PC++

```
{
  signal: [
	{name: "CLK", wave: "lhlhlh"},
	{},
	{name: "Begin instruction sequence (non-flow-ctrl)", wave: "lh.l.."},
	{name: "Post-adder latch OE", wave: "lh.l.."},
	{name: "Pre-adder latch CLK", wave: "l.h.l."},
    {name: "Load Instruction", wave: "l..h.l"}
  ],
	edge: []
}
```

## Instruction sequences

NOTE: Even flow-control instructions must set "Instruction Done" high again so that the "Load instruction" sequence will continue to load the new instruction w/o being deadlocked.

### MOVE & WRITE

Refer to "bus.md" for move timing

Fastest possible case
```
{
  signal: [
    {name: "CLK", wave: "lhlhl"},
	{},
	{name: "Begin instruction sequence (MOVE/WRITE)", wave: "lh.l."},
	{},
    {name: "Bus move", wave: "lh.l.", node: ".a"},
    {name: "Move done", wave: "l...h", node: "....b"},
	{name: "Instruction done", wave: "l...h"}
  ],
  edge: ["a~>b Move delay"]
}
```

### GOTO (flow-control)

```
{
  signal: [
    {name: "CLK", wave: "lhlhl"},
	{},
	{name: "Begin instruction sequence (GOTO)", wave: "lh.l."},
	{},
	{name: "GOTO latches OE", wave: "lh.l."},
	{name: "Pre-adder latch CLK", wave: "l.h.l"},
    {name: "Load Instruction", wave: "l..h."}
  ],
  edge: []
}
```

### GOTO-IF (flow-control)

```
{
  signal: [
    {name: "CLK", wave: "lhlhl"},
	{},
	{name: "Begin instruction sequence (GOTO-IF)", wave: "lh.l."},
	{},
	{name: "GOTO latches OE", wave: "l2.l.", data: ["DECIDER"]},
	{name: "Post-adder latch OE", wave: "l2.l.", data: ["!DECIDER"]},
	{name: "Pre-adder latch CLK", wave: "l.h.l"},
    {name: "Load Instruction", wave: "l..h."}
  ],
  edge: []
}
```

### HALT

```
{
  signal: [
    {name: "CLK", wave: "lhlh"},
	{},
	{name: "Begin instruction sequence (HALT)", wave: "lh.l"},
	{name: "Instruction done", wave: "l.h."}
  ],
  edge: []
}
```

### CALL (flow-control)

```
{
  signal: [
    {name: "CLK", wave: "lhlhlhlhl"},
	{},
	{name: "Begin instruction sequence (CALL)", wave: "lh.l....."},
	{},
	{name: "Call stack - Push", wave: "lh.l....."},
    {name: "Interrupt in-progress", wave: "l.2......", data: ["Bit 4"]},
	{name: "Post-adder latch OE", wave: "l.h..l..."},
	{name: "GOTO latches OE", wave: "l....h.l."},
	{name: "Pre-adder latch CLK", wave: "l.....h.l"},
    {name: "Load Instruction", wave: "l......h."}
  ],
  edge: []
}
```

### RETURN (flow-control)

There is a signal `Instruction++` that should always remain high except in the case of returning from an interrupt so that the interrupted instruction can still be run.

```
{
  signal: [
    {name: "CLK", wave: "lhlhl"},
	{},
	{name: "Begin instruction sequence (RETURN)", wave: "lh.l."},
	{},
	{name: "Call stack - Pop & OE", wave: "lh.l."},
    {name: "Interrupt in-progress", wave: "h.2..", data:["!Bit 4"]},
	{name: "Pre-adder latch CLK", wave: "l.h.l"},
    {name: "Load Instruction", wave: "l..h."},
	{name: "Instruction++", wave: "h.2.h", data:["!Bit 4"]}
  ],
  edge: []
}
```

### CONFIG-INT

```
{
  signal: [
    {name: "CLK", wave: "lhlhl"},
	{},
	{name: "Begin instruction sequence (CONFIG-INT)", wave: "lh.l."},
	{},
	{name: "Interrupt enabled S / R", wave: "l.h.l"},
	{name: "Instruction done", wave: "l.h.."}
  ],
  edge: []
}
```

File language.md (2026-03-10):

# Language

The assembly language closely reflects the actual instructions that it will be converted into. Instructions consist of tokens which can be assembly words (defined in `assembler_config/config.json`) and literal values such as `0x42` or `0b0101`. Instructions and macros are seperated by simicolons (`;`) and all whitespace is ignored except for spaces between instruction tokens. Anything after `#` on a line is treated as a comment.

## Macros

Macros are a way to simplify common parts of the program and to make calling functions easier. A macro consists of a name starting with `@` which is made out of identifier characters followed by parenthesis (`()`) with comma-seperated arguments inside them.

### Anchors

Anchors mark a place in a program that may be `call`ed to `goto`ed to, for example:

```
@anchor(function_name)
```

marks the beginning of a function. An anchor can also mean other things such as the beginning of a loop or the end of an if-statement. To go to an achor, use:

```
@call(function_name)
```

which will be expanded to three instructions: `write 0xXX goto-a`, `write 0xXX goto-b`, `call` where it will write the correct address to the GOTO A & B latches. `@goto(_)` and `goto_if(_)` work in the exact same way.

For version 2: `@set_interrupt(_)` will use the given anchor name to setup the interrupt goto latches.

### Write string

Another macro is `@write_string("Hello world")` which will write each character of the given string (in ASCII) to the GPRAM starting at wherever the address is currently set to.

### Get anchor address

Sometimes it is necessary to access the address of an achor without using any flow control macros. This is why there is the `@push_anchor_address(anchor_name)` macro. It will push two bytes onto the stack, starting with address bits 0 - 7 then 8 - 15.

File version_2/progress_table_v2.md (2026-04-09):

# Progress table (for version 2)

| PCB | Timing diagram(s) completed | Built in RustyLogic | Gates numbered | KiCad Schematic verified | Parts list updated | KiCad PCB | PCB built/aquired | Assembled | Tested |
| - | - | - | - | - | - | - | - | - | - |
| Main sequencer | Done | Done | Done | Done | TODO | TODO | TODO | TODO | TODO |
| Call stack | Done | Done | Sequencer only | Done | TODO | TODO | TODO | TODO | TODO |
| Prog memory module | Not needed | Not needed | Not needed | Done | TODO | TODO | TODO | TODO | TODO |
| Ctrl unit main board | Not needed | In toplevel | Done | Done | TODO | TODO | TODO | TODO | TODO |
| Bus Sequencer | Done | Done | Done | Done | TODO | TODO | TODO | TODO | TODO |
| Bus (Motherboard) | Not needed | In toplevel | Not needed | Done | TODO | TODO | TODO | TODO | TODO |
| Start pulse generator | Not needed | Done | Done | Done | TODO | TODO | TODO | TODO | TODO |
| ALU | Not needed | Done | Bus timing only | Done | TODO | TODO | TODO | TODO | TODO |
| Stack controller data/main | Not needed | Done | Not needed | Done | TODO | TODO | TODO | TODO | TODO |
| Stack controller sequencer | Done | Done | Done | TODO | TODO | TODO | TODO | TODO | TODO |
| GPRAM sequencer & address | Done | Done | Sequencer only | TODO | TODO | TODO | TODO | TODO | TODO |
| GPRAM Shared memory | Not needed | Done | Done | TODO | TODO | TODO | TODO | TODO | TODO |
| I/O controller | Done | Done | Sequencer only | TODO | TODO | TODO | TODO | TODO | TODO |
| Vector digital board | Done | Done | Done | TODO | TODO | TODO | TODO | TODO | TODO |
| Timers | Not needed | Done | Done | TODO | TODO | TODO | TODO | TODO | TODO |
| Interrupt handler data/main | Not needed | Done | Done | TODO | TODO | TODO | TODO | TODO | TODO |
| Interrupt sequencer | Done | Done | Done | TODO | TODO | TODO | TODO | TODO | TODO |
| CLK / Control panel | Not needed | Not needed | Not needed | TODO | TODO | TODO | TODO | TODO | TODO |
| Global state LED board | Not needed | Not needed | Not needed | TODO | TODO | TODO | TODO | TODO | TODO |

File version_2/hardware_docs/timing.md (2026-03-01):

# All Timing diagrams go here

The shortest possible cycle is 2 clock cycles.

## Memory read delays

For flash whichever is highest of:
* TCE (chip enable) = 70 ns
* TOE (output enable) = 35 ns
* TOH (hold from address change), maximum unspecified

For RAM whichever is highest of:
* TACE (chip enable) = 55 ns
* TOE (output enable) = 30 ns
* TAA (hold from address change) = 55 ns

## RAM Write delay

* TDW (data valid before write) = 25 ns
* TAW - TDW (address set before write) = 50 ns - 25 ns = 25 ns

Conclusion: These times are comparable to other logic devices so no extra clock cycles needed.

Paste into https://wavedrom.com/editor.html

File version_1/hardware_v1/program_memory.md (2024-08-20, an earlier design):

# Program memory

The program memory board will use 2 <a href="https://ww1.microchip.com/downloads/en/DeviceDoc/20005022C.pdf">128k x 8 bit flash memory chips</a> in parallel to make up 16-bit instruction words.

## Reading

There will be a header connecting the program memory board to the control unit main board with all 16 address and 16 data (instruction) bits.

## Writing

An Arduino board will be used for writing to the program memory.

### Timing

The clock signal from the arduino will have a frequency of 1 MHz. It will be used for clocking each new word into the input shift register and running the chip-erase and byte-program sequences.

### NOTE: The timing diagrams are old and not accurate anymore

Chip write sequences: 

Program write arduino side timing diagram:
```
{
  signal: [
    {name: "Clk", wave: "n..|...|..."},
    {name: "Chip erase", wave: "lhl|...|...", node: ".a"},
    {name: "Byte program", wave: "l..|.hl|.hl", node: ".....b...c"},
    {},
    {name: "Data", wave: "x2222222222", data: ["0", "1", "...", "7", "0", "1", "...", "7", "0", "1"]}
  ],
  edge: []
}
```

Internal timing diagram (Chip erase):
```
{
  signal: [
    {name: "Clk", wave: "hlhlhlhlhlhlhlhl"},
    {name: "Chip erase", wave: "lh.l............"},
    {name: "Byte program", wave: "l..............."},
    {},
    {name: "Shift registers", wave: "9.9.9.9.9.9.9.9."},
    {name: "Shift registers latch OE", wave: "l..............."},
    {name: "Data program OE", wave: "l..h...........l"},
    {name: "Data", wave: "x..2.2.2.2.2.2.x", data: ["0xAA", "0x55", "0x80", "0xAA", "0x55", "0x10"]},
    {name: "Address counter CLR", wave: "lh.l............"},
    {name: "Address counter OE", wave: "l..............."},
    {name: "Address program OE", wave: "l.h...........l."},
    {name: "Address", wave: "x.2.2.2.2.2.2.x.", data: ["0x5555", "0x2AAA", "0x5555", "0x5555", "0x2AAA", "0x5555"]},
    {name: "WE#", wave: "h..lhlhlhlhlhlh."},
  ],
  edge: []
}
```

Internal timing diagram (Byte program):
```
{
  signal: [
    {name: "Clk", wave: "hlhlhlhlhlhlhlhlhlhl"},
    {name: "Chip erase", wave: "l..................."},
    {name: "Byte program", wave: "l........h.l........"},
    {name: "D 8-15 & 0-7", wave: "x2.2.2.2.2.2.2.2.x.x", data: ["15&7", "14&6", "13&5", "12&4", "11&3", "10&2", "9&1", "8&0"]},
    {},
    {name: "Shift registers", wave: "9.9.9.9.9.9.9.9.2.9.", data: ["", "", "", "", "", "", "", "", "<data>"]},
    {name: "Shift registers latch CLK", wave: "l................h.l"},
    {name: "Shift registers latch OE", wave: "l................h.l"},
    {name: "Data program OE", wave: "l..........h.....l.."},
    {name: "Data", wave: "x..........2.2.2.2.x", data: ["0xAA", "0x55", "0xA0", "<data>"]},
    {name: "Address counter CLR", wave: "l..................."},
    {name: "Address counter OE", wave: "l...............h.l."},
    {name: "Address program OE", wave: "l.........h.....l..."},
    {name: "Address", wave: "x.........2.2.2.2.x.", data: ["0x5555", "0x2AAA", "0x5555", "<addr>"]},
    {name: "WE#", wave: "h..........lhlhlhlh."},
  ],
  edge: []
}
```

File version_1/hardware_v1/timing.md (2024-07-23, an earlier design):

# Timing

There will be 3 clock signals: A, B, and combined (ORed). They can all be described by a 4-part cycle:

| A | B | Combined |
| - | - | - |
| 0 | 0 | 0 |
| 1 | 0 | 1 |
| 0 | 0 | 0 |
| 0 | 1 | 1 |

Various devices in the computer will interact with each other using strictly different clocks (A and B) so as to make it simple to prevent race conditions. Devices' internal logic can be run on the combined clock if necessary to make it faster.

## Startup

There will be a signal sent to everything on the bus called 'enable', when low it will disable most timing logic and all bus-write outputs. On startup, 'enable' should be kept low for many clock cycles (probably like 10) then set high on B CLK. Then the 'start' signal from the startup controller to the control unit will be set on the rising edge of A CLK for 1 cycle.

The startup controller will have a capacitor charged by a resistor which will set two digital signals using op-amps. The signals will be 'reset' which will start high then quickly go low, and the 'enable' signal will start low and come on some time after startup. Once the 'set' signal is high, a sequence will run to set the 'enable' line high and then start the control unit. There should be a MOSFET to immediately discharge the capacitor upon power off to prevent transient power-loss from triggering an enable-start sequence without enough clock cycles.

Wavedrom source:
```
{
  signal: [
    {name: "Clk comb.", wave: "p......"},
    {name: "Clk A", wave: "plplplp"},
    {name: "Clk B", wave: "lplplpl"},
    {},
    {name: "Enable (read on B CLK)", wave: "lh....."},
    {name: "Start", wave: "l.h.l.."}
  ],
  edge: []
}
```

## Bus timing

| Line(s) | Controlled by | Clock set | Read by | Clock read |
| - | - | - | - | - |
| Write | Bus arbiter | A | Writing device | B |
| Read | Bus arbiter | B | Reading device | A |
| Read ready | Writing device | B | Bus arbiter | A |
| D0 - D7 | Writing device | B | Reading device | A |



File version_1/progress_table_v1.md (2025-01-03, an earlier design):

# Progress table (for version 2)

| Circuit | Timing diagram(s) completed | Built in Circuitverse | KiCad Schematic verified | Parts list updated | KiCad PCB | PCB built/aquired | Assembled | Tested |
| - | - | - | - | - | - | - | - | - |
| Ctrl unit central timing | Done | Done | Redesign | Done | - | - | - | - |
| Call stack | Done | Done | Done | Done | Done | - | -| - |
| Prog memory module | Done | Not needed | Redesign (Done) | Done | Done | - | - | - |
| Ctrl unit main board | Not needed | Done | Done | Done | Done | - | - | - |
| Bus/Motherboard | Done | Done | Done | Done | Done | - | - | - |
| Startup controller | Done | Done | Done | Done | Done | - | - | - |
| ALU | Not needed | Done | Done | Done | Done | - | - | - |
| Clock | Done | Done | Redesign (Done) | Done | Done | - | - | - |
| Stack controller | Done | Done | Redesign | Done | - | - | - | - |
| GPRAM controller | Done | Done | Done | Done | Done | - | - | - |
| I/O controller | Not needed | Done | Redesign (Done) | Done | Done | - | - | - |
| LED Display | Done | Done | Done | Done | - | - | - | - |
| LED Display (Controller) | Done | Done | Done | Done | - | - | - | - |

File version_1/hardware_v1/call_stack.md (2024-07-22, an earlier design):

# Call stack

The call stack will be a 256 x 16 bit stack memory reading inputs on the A clock and connected to the control unit for storing and retrieving return addresses for the `CALL` and `RETURN` instructions. For memory chips it will have 2 32k x 8 bit memories wired in parellel (for 16-bit word size). Since only 256 words will be needed, the extra addresses will be tied to GND. It may be expanded in the future.

## Timing

### Push

```
{
  signal: [
    {name: "Clk comb.", wave: "p......"},
    {name: "Clk A", wave: "plplplp"},
    {name: "Clk B", wave: "lplplpl"},
    {},
    {name: "Push", wave: "lh.l..."},
    {name: "Input latch CLK", wave: "l.h.l.."},
    {name: "Pre-adder latch CLK", wave: "l.h.l.."},
    {name: "Post-adder latch CLK", wave: "l..h.l."},
    {name: "Input latch OE", wave: "l..h.l."},
    {name: "Write", wave: "l...pl."}
  ],
  edge: []
}
```

### Pop

```
{
  signal: [
    {name: "Clk comb.", wave: "p......"},
    {name: "Clk A", wave: "plplplp"},
    {name: "Clk B", wave: "lplplpl"},
    {},
    {name: "Pop", wave: "lhpl..."},
    {name: "Read", wave: "lhpl..."},
    {name: "Output latch CLK", wave: "lnhpl.."},
    {name: "Pre-adder latch CLK", wave: "l.h.l.."},
    {name: "Post-adder latch CLK", wave: "l..h.l."},
    {name: "Inc (0) / Dec (1) select", wave: "l.h.l.."}
  ],
  edge: []
}
```

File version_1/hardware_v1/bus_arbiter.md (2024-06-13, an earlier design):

# Bus arbiter

The bus arbiter will read its control signals from the control unit during the A clock, therefore the control unit will use the B clock to comminicate with it.

These are the control lines between the control unit and the bus arbiter:
| Line(s) | Controlled by | Clock set | Read by | Clock read |
| - | - | - | - | - |
| Move | Control unit | B | Bus arbiter | A |
| Write address | Control unit | B | Bus arbiter | A |
| Read address | Control unit | B | Bus arbiter | A |
| Done | Bus arbiter | A | Control unit | B |

Wavedrom source for normal bus transfer
```
{
  signal: [
    {name: "Clk comb.", wave: "p........"},
    {name: "Clk A", wave: "plplplplp"},
    {name: "Clk B", wave: "lplplplpl", node: "...a"},
    {},
    {name: "Move", wave: "lh.....l.", node: ".......d"},
    {name: "Write address", wave: "x2.....x.", data: ["A0 - A3"]},
    {name: "Read address", wave: "x2.....x.", data: ["A0 - A3"]},
    {name: "Done", wave: "l.....h.l", node: "......c"},
    {},
    {name: "Read", wave: "l....h.l."},
    {name: "Write", wave: "l.h.....l"},
    {name: "Read ready", wave: "l....h.l.", node: ".....b"},
    {name: "D0 - D7", wave: "x....2.x.", data: ["data"]}
  ],
  edge: ['a~>b Writing device delay', 'c~>d']
}
```

## Same device read/write

There will be times when it is convenient or necessary for the same device to write to the bus and simultaneously read from it. That may cause issues with internal timing that will likely be hard to engineer around. For this reason the bus arbiter will have a feature to send the write signal, store the bus value, wait, and then send the stored bus value by asserting the read signal 2 B-clock periods later then normal. This will only happen if the reading and writing device is the same.

Wavedrom source for delayed bus transfer
```
{
  signal: [
    {name: "Clk comb.", wave: "p............"},
    {name: "Clk A", wave: "plplplplplplp"},
    {name: "Clk B", wave: "lplplplplplpl", node: "...a"},
    {},
    {name: "Move", wave: "lh.........l.", node: "...........d"},
    {name: "Write address", wave: "x2.........x.", data: ["A0 - A3"]},
    {name: "Read address", wave: "x2.........x.", data: ["A0 - A3"]},
    {name: "Done", wave: "l.........h.l", node: "..........c"},
    {},
    {name: "Data save latch clock", wave: "l.....pl....."},
    {name: "Data save latch OE", wave: "l........h.l."},
    {},
    {name: "Read", wave: "l........h.l.", node: ".........e"},
    {name: "Write", wave: "l.h.....l...."},
    {name: "Read ready", wave: "l....h.l.....", node: ".....b"},
    {name: "D0 - D7", wave: "x....2.x.2.x.", data: ["data", "data"]}
  ],
  edge: ['a~>b Writing device delay', 'c~>d', 'b~>e 2 B-clock cycles']
}
```

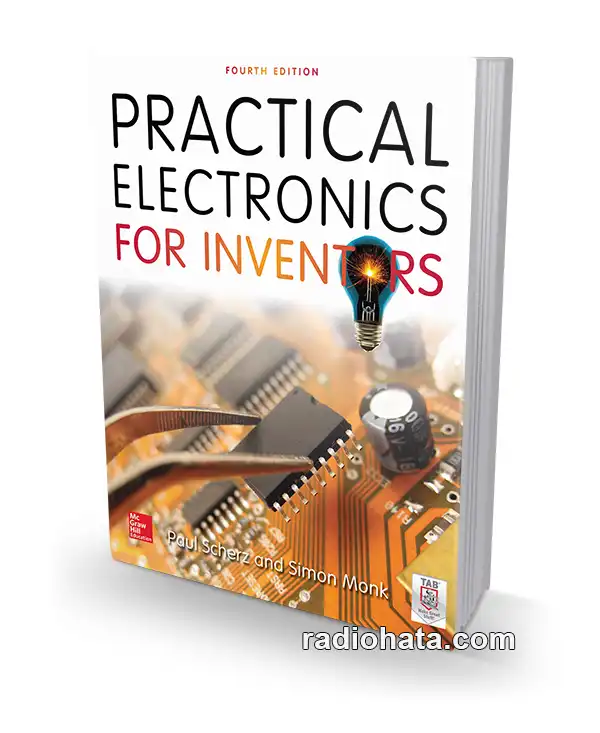
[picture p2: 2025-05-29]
presentation/images/practical_electronics.webp

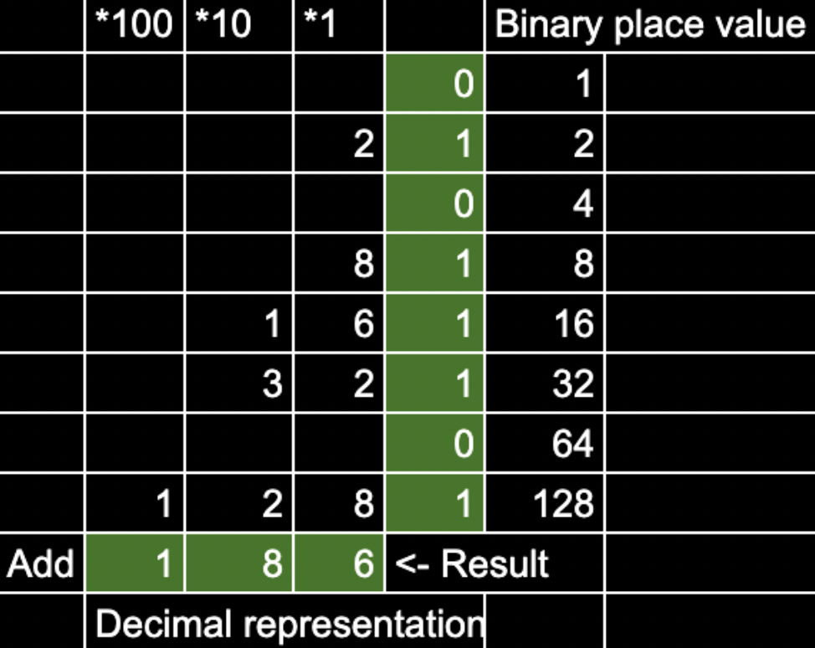
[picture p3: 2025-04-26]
presentation/images/bin_to_dec_gsheets.png

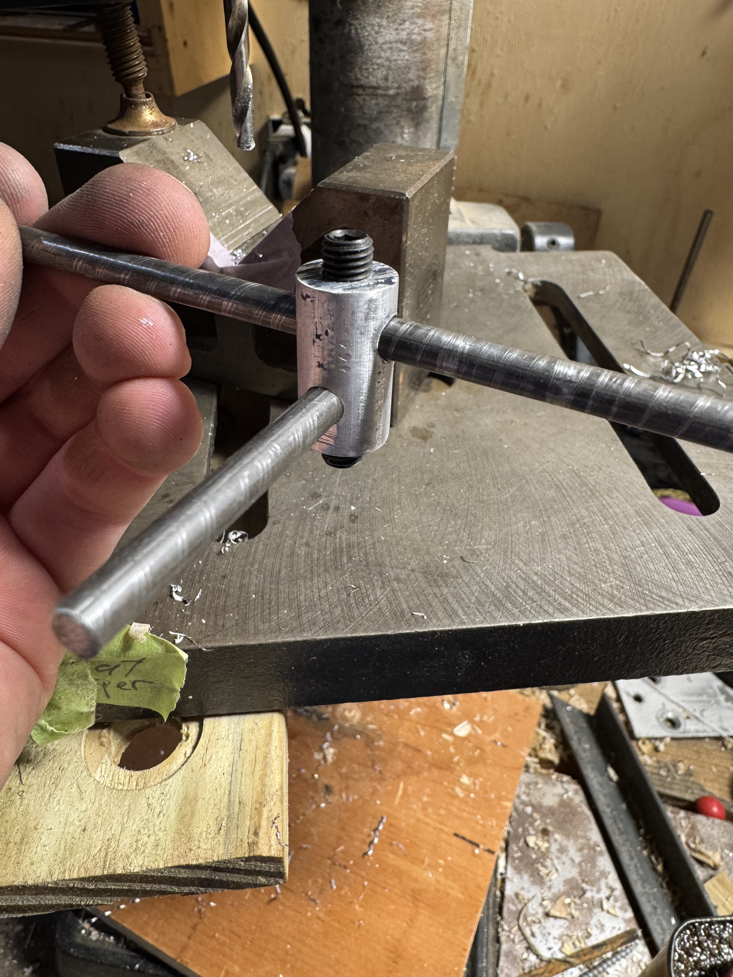
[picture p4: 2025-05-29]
presentation/images/bracket.jpeg

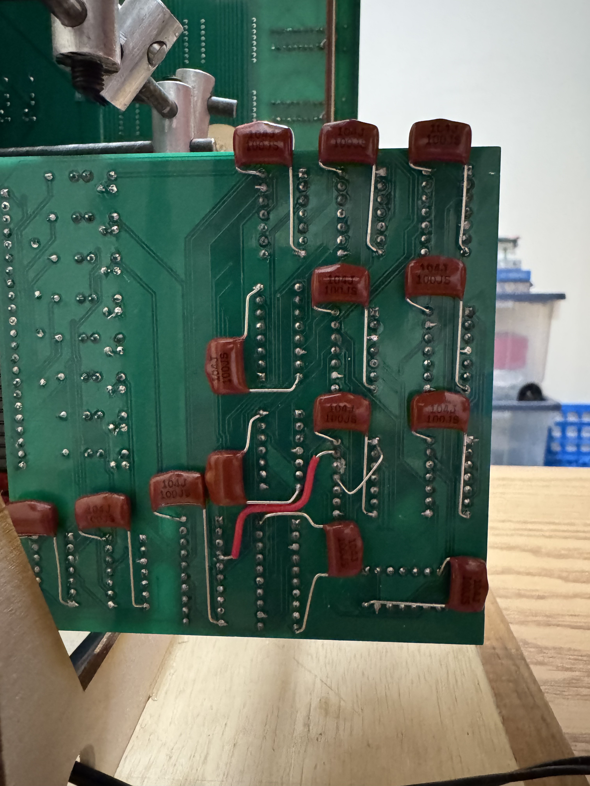
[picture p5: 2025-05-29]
presentation/images/back_of_timing.jpeg

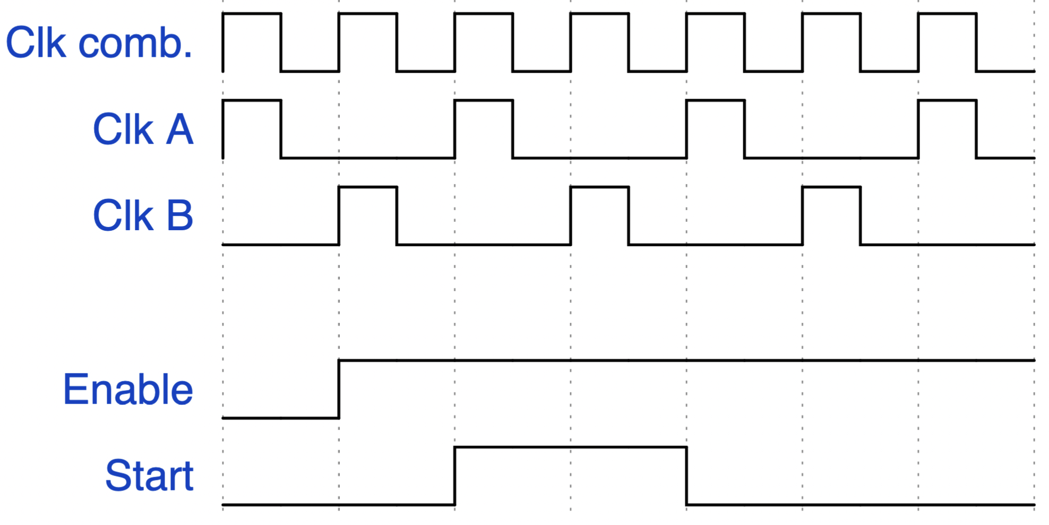
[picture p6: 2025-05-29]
presentation/images/wavedrom_start_timing.png

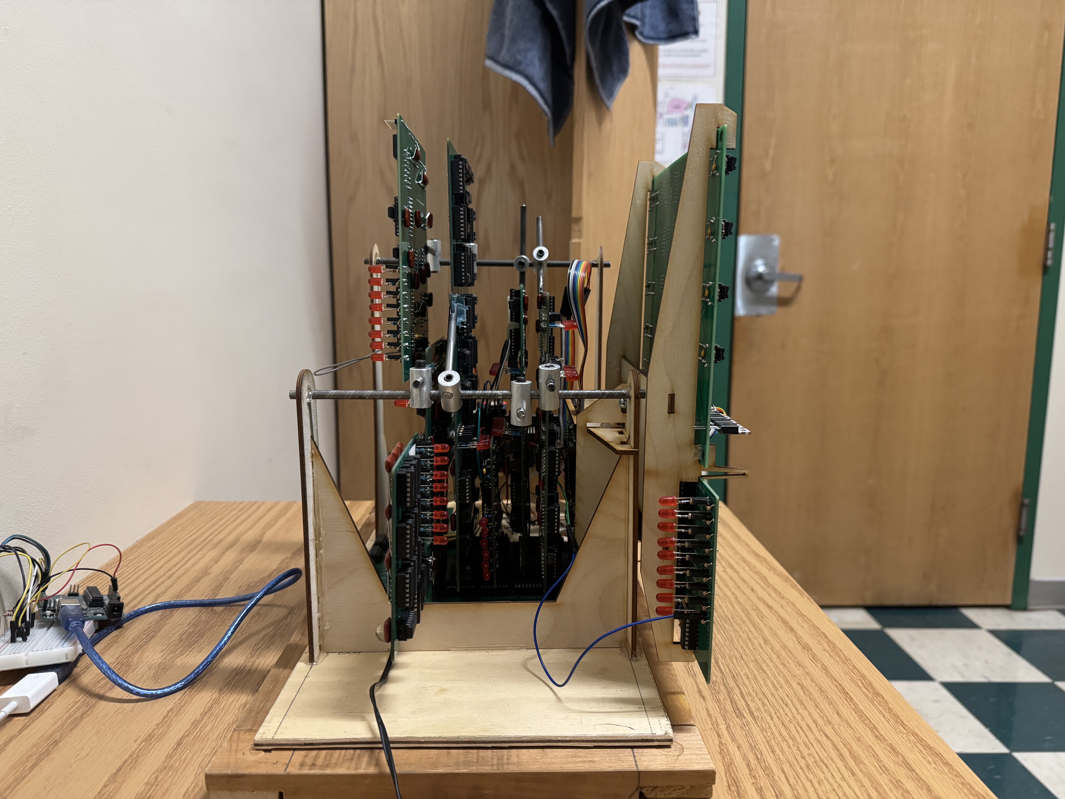
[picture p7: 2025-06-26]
presentation/images/side_view.jpeg

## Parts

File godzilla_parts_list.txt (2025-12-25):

Parts list:
Battery holder 2032: 123-A-BAT-CH-C8-EA-ZTP1-ND
555: LMC555CN/NOPB-ND
SMD LEDs, red: SML-D12U1WT86CT-ND
Capacitor: 399-18273-ND

Design:

Lights flash red
Battery from 2.6 to 3 volts, <20 mA for LEDs. Testing results mean 100 Ohms in series w/ each LED is best and results in 10 mA which is still bright.

555 circuit: https://www.electronics-tutorials.ws/waveforms/555_oscillator.html
Period: ~ 2 secs, R2 = 470k, R1 = 10k, C = 2 uF

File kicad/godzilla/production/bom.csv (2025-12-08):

Designator | Footprint | Quantity | Value | LCSC Part #
BT1 | battery_holder_coin | 1 | Battery_Cell
C1 | CP_Radial_D4.0mm_P2.00mm | 1 | C
D1, D2 | 0603 | 2 | LED
R1, R2, R3, R4 | 0.4_pitch_resistor | 4 | R
U1 | DIP-8_W7.62mm | 1 | NE555P

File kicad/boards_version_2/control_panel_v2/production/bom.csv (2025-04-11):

Designator | Footprint | Quantity | Value | LCSC Part #
C1 | CP_Radial_D5.0mm_P2.50mm | 1 | C
C2, C3, C4, C5, C6 | C_Rect_L11.0mm_W4.2mm_P10.00mm_MKT | 5 | C
D1, D2, D3 | LED_D3.0mm | 3 | LED
J1, J2, J3, J4 | PinHeader_1x01_P2.54mm_Vertical | 4 | Conn_01x01_Pin
R1, R10, R11, R12, R13, R2, R3, R4, R5, R6, R7, R8, R9 | 0.4_pitch_resistor | 13 | R
RV1 | panel_mount_pot | 1 | R_Potentiometer
SW1 | SW_PUSH_6mm | 1 | SW_Push
SW2, SW3, SW4, SW5, SW6, SW7 | 2_pin_button | 6 | SW_Push
U1, U12, U13, U3, U9 | PinHeader_1x02_P2.54mm_Vertical | 5 | ~
U10, U11 | crystal_dip_14 | 2 | ~
U14 | DIP-14_W7.62mm | 1 | ~
U15, U16, U19, U20, U22 | PinHeader_1x08_P2.54mm_Vertical | 5 | ~
U17 | manual_clock_switch_side | 1 | ~
U18 | PinHeader_1x03_P2.54mm_Vertical | 1 | ~
U2, U4 | DIP-16_W7.62mm | 2 | ~
U21 | PinHeader_1x10_P2.54mm_Horizontal | 1 | ~
U5, U6, U7, U8 | PinHeader_1x16_P2.54mm_Vertical | 4 | ~

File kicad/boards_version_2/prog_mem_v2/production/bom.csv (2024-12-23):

Designator | Footprint | Quantity | Value | LCSC Part #
D1 | D_A-405_P7.62mm_Horizontal | 1 | D
R1, R10, R2, R3, R4, R5, R6, R7, R8, R9 | 0.4_pitch_resistor | 10 | 10k
U1, U7 | DIP-32_W15.24mm | 2 | ~
U10, U11, U13, U14, U16, U21, U5, U8 | DIP-20_W7.62mm | 8 | ~
U12, U32, U33, U38, U4, U6, U9 | DIP-14_W7.62mm | 7 | ~
U15, U17, U18, U20, U22, U23, U24, U25 | jumper | 8 | ~
U19 | PinHeader_1x16_P2.54mm_Vertical | 1 | ~
U2 | PinHeader_1x39_P2.54mm_Vertical | 1 | ~
U3 | PinHeader_1x10_P2.54mm_Horizontal | 1 | ~

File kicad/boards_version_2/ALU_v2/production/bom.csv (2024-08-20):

Designator | Footprint | Quantity | Value | LCSC Part #
R1, R2, R3, R4, R5 | 0.4_pitch_resistor | 5 | 10k
U1 | PinHeader_1x04_P2.54mm_Vertical | 1 | ~
U10, U11, U12, U18, U19, U21, U23, U24, U25, U27, U28, U39, U40, U41, U42, U50, U51, U52, U53, U54, U9 | DIP-14_W7.62mm | 21 | ~
U13, U15, U30, U31, U32, U33, U34, U35, U36, U37, U7, U8 | DIP-16_W7.62mm | 12 | ~
U14, U16, U17, U20, U22, U26, U29, U38, U4, U43, U44, U45, U5, U6 | DIP-20_W7.62mm | 14 | ~
U2 | PinHeader_1x23_P2.54mm_Vertical | 1 | ~
U3 | PinHeader_1x30_P2.54mm_Horizontal | 1 | ~
U46, U47, U48, U49 | jumper | 4 | ~

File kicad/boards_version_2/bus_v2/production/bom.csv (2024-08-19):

Designator | Footprint | Quantity | Value | LCSC Part #
J1 | BarrelJack_Horizontal | 1 | Barrel_Jack
R1, R10, R11, R13, R14, R2, R3, R4, R5, R6, R7, R8, R9 | 0.4_pitch_resistor | 13 | 1k
U1 | PinHeader_1x11_P2.54mm_Vertical | 1 | ~
U10, U11, U12, U13 | DIP-16_W7.62mm | 4 | ~
U14, U16, U23, U25, U28, U30, U31, U8, U9 | DIP-14_W7.62mm | 9 | ~
U15 | DIP-20_W7.62mm | 1 | ~
U17, U18, U19, U20, U21, U22, U26, U27, U32, U33 | jumper | 10 | ~
U2, U24, U3, U4, U5, U6, U7 | PinHeader_1x23_P2.54mm_Vertical | 7 | ~
U29 | TO-220-3_Vertical | 1 | L7805
U34 | PinHeader_1x07_P2.54mm_Vertical | 1 | ~

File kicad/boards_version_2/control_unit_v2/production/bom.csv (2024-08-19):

Designator | Footprint | Quantity | Value | LCSC Part #
D1, D2, D3, D4 | LED_D4.0mm | 4 | LED
R10, R11, R12, R13, R14, R15, R16, R17, R18, R19, R2, R20, R21, R22, R3, R4, R5, R6, R7, R8, R9 | 0.4_pitch_resistor | 21 | 10k
U1 | PinHeader_1x23_P2.54mm_Vertical | 1 | ~
U10, U13, U15, U18, U21 | DIP-16_W7.62mm | 5 | ~
U11 | PinHeader_1x23_P2.54mm_Horizontal | 1 | ~
U12, U14, U16, U20, U4 | DIP-14_W7.62mm | 5 | ~
U17 | PinHeader_1x39_P2.54mm_Vertical | 1 | ~
U19, U24, U5, U6, U7, U8, U9 | DIP-20_W7.62mm | 7 | ~
U2 | PinHeader_1x11_P2.54mm_Vertical | 1 | ~
U22 | PinHeader_1x04_P2.54mm_Vertical | 1 | ~
U23, U25 | jumper | 2 | ~
U3 | PinHeader_1x24_P2.54mm_Vertical | 1 | ~

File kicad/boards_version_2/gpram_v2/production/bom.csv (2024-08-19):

Designator | Footprint | Quantity | Value | LCSC Part #
R1, R2, R3, R4, R5, R6, R7, R8, R9 | 0.4_pitch_resistor | 9 | 10k
U1 | PinHeader_1x23_P2.54mm_Vertical | 1 | ~
U10, U13, U14, U15, U16, U25, U26, U3, U39, U40, U5, U9 | DIP-20_W7.62mm | 12 | ~
U11, U12, U7, U8 | DIP-16_W7.62mm | 4 | ~
U17, U2 | DIP-28_W15.24mm | 2 | ~
U18, U19, U20, U21, U22, U23, U27, U28, U29, U30, U31, U32, U33, U43 | jumper | 14 | ~
U24, U34, U35, U36, U37, U38, U4, U41, U42, U44, U46, U47, U6 | DIP-14_W7.62mm | 13 | ~

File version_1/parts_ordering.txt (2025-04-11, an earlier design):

Digi-key order 2024-6-25

5,296-2033-5-ND
2,TC74HC08APF-ND
3,TC74HC574APF-ND
4,296-3580-5-ND
3,1450-1033-ND
1,296-2108-5-ND
1,296-2063-5-ND
10,AE9989-ND
5,A120349-ND
3,2057-ICS-320-T-ND
3,473-1007-ND

Digi-key order 2024-8-23

296-2033-5-ND
TC74HC08APF-ND
TC74HC574APF-ND
296-3580-5-ND
SST39SF010A-70-4C-PHE-ND
1450-1033-ND
296-2108-5-ND
TC74HC04APF-ND
296-1599-5-ND
AE9989-ND
A120349-ND
2057-ICS-320-T-ND
AE10264-ND
2057-ICS-628-T-ND
ED3053-5-ND
3M5484-ND
296-2106-5-ND
296-33899-5-ND
296-33119-5-ND
296-4345-5-ND
296-1596-5-ND
296-12788-5-ND

12
18
17
1
0
0
2
19
1
56
12
36
0
0
1
0
8
2
4
0
19
4

12,296-2033-5-ND
18,TC74HC08APF-ND
17,TC74HC574APF-ND
1,296-3580-5-ND
2,296-2108-5-ND
19,TC74HC04APF-ND
1,296-1599-5-ND
56,AE9989-ND
12,A120349-ND
36,2057-ICS-320-T-ND
1,ED3053-5-ND
8,296-2106-5-ND
2,296-33899-5-ND
4,296-33119-5-ND
19,296-1596-5-ND
4,296-12788-5-ND

Digi-key order 2024-10-12

3,TC74HC08APF-ND
4,AE9989-ND
4,A120349-ND
250,S9001-ND
2,TC74HC04APF-ND
2,296-3580-5-ND
1,1568-1511-ND
1,1528-1967-ND

Digi-key order 2025-1-9

36,AE9989-ND
10,A120349-ND
20,2057-ICS-320-T-ND
2,2057-ICS-628-T-ND
2,ED3053-5-ND
2,296-2033-5-ND
4,TC74HC08APF-ND
9,TC74HC574APF-ND
2,1450-1033-ND
3,TC74HC04APF-ND
1,296-2062-ND
2,296-1599-5-ND
2,296-25983-5-ND
2,296-2106-5-ND
1,296-1596-5-ND
8,MAX6971ANG+-ND
8,BS170-ND
1,296-3580-5-ND

Digi-Key 2025-4-5
2,296-1599-5-ND
2,AE9992-ND
1,AE9989-ND
5,296-1391-5-ND
1,110-MXO45-3C-8M000000-ND
1,X126-ND
1,987-1718-ND
8,FQP20N06L-ND
10,BC2665CT-ND
4,IRF3205PBF-ND

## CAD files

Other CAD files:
version_1/computer_supports.FCStd

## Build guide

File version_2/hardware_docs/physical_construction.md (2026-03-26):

# Physical construction for V2

There will be 1 "base board" horizontal along the very buttom which will be the bus board which everything connects to vertically. The startup controller will also be horizontal and connected to the bus board.

## Vertical layers

Starting from the control unit module and ending at the I/O controller

| Board | Connected to bus | Additional buttom connections | Additional connections | Notes |
| - | - | - | - | - |
| Bus Sequencer | Not usual connection | No | No | Vertically oriented, one connection to motherboard |
| Main sequencer | No | No | Control unit main | Sits alongside call stack |
| Call stack | No | No | Control unit main | Sits alongside main sequencer |
| Control unit main | Yes | Controls mostly bus TX/RX addresses | ALU Opcode, Main sequencer, call stack, prog mem interface | Connected to 3 other boards besides bus |
| Prog memory module | Yes | No | Control unit main, GPRAM access controller module, Programming interface | None |
| GPRAM Shared memory | Yes | No | Prog mem module, GPRAM Sequencer & address | None |
| GPRAM sequencer & address | Yes | No | GPRAM Shared memory | None |
| ALU | Yes | No | Control unit main board for opcode | None |
| Stack sequencer | No | No | Stack (data) | Only attatched to stack main |
| Stack data/main | Yes | No | Stack sequencer | None |
| Interrupt sequencer | No | No | Interrupt handler data/main | None |
| Interrupt handler data/main | Yes | No | Interrupt active to control unit main sequencer, Front panel interrupts, Timer interrupts | None |
| Timers | Yes | No | Interrupt handler data/main for timer interrupts | Has internal 1 MHz clock |
| Vector digital board | Yes | No | Vector analog board (not yet designed) | None |
| I/O controller | Yes | No | No | Actually horizontal and will stick out to the side for easy pin access |

## Other boards

* Start pulse generator - Small circuit to generate start pulses that are updated on the + and - clock edges whenever the global `Enable` signal goes high.
* Base board - Bus timing and connections to almost everything else
* CLK / Control panel - Clock source & divider select, manual clock stepping, power switch, programming connection, interrupt connections, etc
* Global state LED panel - LEDs that show timing states from all other boards. There will be a lot of silkscreen graphics and labels. This board will have a lot of connections using 0.1" connectors.

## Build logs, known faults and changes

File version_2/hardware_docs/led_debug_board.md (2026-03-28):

# LED Debug Board

This board will have all the state LEDs on it along with a lot of silkscreen text/grahics showing what they mean. Most boards (especially sequential ones) will have a set of jumpers and an associated pin header specifically to connect those debug signals to this board.

## Internal debug signals

These are lists of jumpers and connections to the global state LED board that are internal to the circuit and not connected to any outputs. Internal debug signals all use the "Jumper V2 gnd" symbol, except when the signal going in might by set by a pullup resistor. They will be connected before the corresponding jumpers and put through buffers to reduce possibility of EMI and slow timing issues.

## Board debug connections

### Main sequencer: (no pullup resistors in use)

Internal debug

0. Begin instruction sequence
1. Early PC++, non-flow-ctrl
2. Interrupt enable
3. Interrupt in-progress
4. Instruction Done
5. Bit 4 save for int call
6. Load Instruction

Output debug:

All 16 sequencer outputs are buffered and sent to the debug board. They are also jumpered with pulldowns.

### Call stack: (no pullup resistors in use)

Internal debug

0. Pointer ++(0) / -- (1)
1. Pre-adder latch CLK
2. Post-adder latch CLK
3. Read
4. Write

### Control unit main: (some pullups)

Internal debug

0. GOTO Decider
1. Opcode (3-bit) 0 (AVOID PULLDOWN)
2. Opcode (3-bit) 1 (AVOID PULLDOWN)
3. Opcode (3-bit) 2 (AVOID PULLDOWN)
4. Instruction bit 4 (AVOID PULLDOWN)
5. PC MSB (AVOID PULLDOWN)
6. Interrupt
7. Instruction load possible

### Program memory

Internal debug

0. Read mode
1. Write mode
2. D 0-7
3. D 8-15
4. A 0-7
5. A 8-15
6. Write interface select (0=bus, 1=external)

### Bus / Bus sequencer

All ORed inputs from all bus connections (TX Ready, etc) (except for Fault) and all outputs from the sequencer will be jumpered on the main board and buffered and sent to the LED debug board.

0. TX Ready/OE/RX
1. RX not ready
2. RX extend to controller
3. Bus save CLK (WARNING: Disabling may cause contention)
4. Bus save OE
5. Move done
6. RX extend from controller
7. Global enable out (from start pulse generator)

Just LEDs without jumpers will be placed alongside each bus slot and indicating for each slot: Fault, RX Extend to controller, RX not ready, TX ready.

### Interrupt handler

0. Interrupt to main sequencer
1. TODO

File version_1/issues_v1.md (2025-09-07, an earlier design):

# Issues

## Board order 1

* The outputs in the dual 4-input OR gate are entered backward in the KiCad symbol, this affects the control unit central timing and the bus. (FIXED FOR VERSION 2)
* The silkscreen LED labels on the central timing board are incorrect. (FIXED FOR VERSION 2)
* The resistor and capacitor on the startup controller analog timer should be swapped
* Whenever there is nothing writing to the program address bus, it is pulled high by the 16 pullup resistors. This is by design for when the computer starts up. The problem is that during a move sequence (and probably most other sequences) the post-adder latch output is disabled meaning the address is all 1s, the problem is that the memory will react instantly, changing for example the bus read/write addresses and probably other things too. Solution: Replace the transparent address latches on the memory board with edge-triggered ones that are triggered by the `program read done` signal. (FIXED FOR VERSION 2)
* Any fault triggered by the central timing board (except the `halt` comand) will not continue the main execution cycle, it will just stop. (IGNORED)
* The bits comming from both of the counters on the clock board are swaped when put on the bus. (FIXED FOR VERSION 2)
* The enable signal on the stack controller board is not connected to the enable pin. (FIXED FOR VERSION 2)
* DO NOT USE 4000B series logic, also >= 4.7k ohm on ALL LEDs. A lot of logic signals are low (like 3 volts) because of LED current draw.
* The post-adder latches for the GPRAM address aren't needed, instead use 10K resistors. This also means the `post adder CLK` and `post adder OE` signals are irrelevent.

### Stack controller timing issues (FIXED FOR VERSION 2)

* The push sequence for incrementing the post-adder clock had an `A-B-A & A` chain, it was chaged to have an `A-B` chain to obey the push timing diagram.
* The stack `pointer (0) / offset (1)` signal from the offset-write sequence had an `A-B-A-B` chain, it was changed to an `A-B` chain to obey the offset-write timing diagram.
* The `input latch output enable` signal from the "push / offset write" sequence was on an `A-B-A-B` chain, it was changed to an `A-B` chain, similarly the `memory write signal` which was part of the same chain was also changed from `A-B-A-B-A & A` to `A-B-A & A`.

## Display write timing issue

It is caused by the the regular update from the input latches to SRAM lining up with the computer updating the data in the input latches. It leads to the same piece of data (1 byte, 8 pixels on the display) getting smeared across two adjacent memory locations and corrupting the image. The way the two 32k x 8 memories are used is: one of them stores even-indexed bytes and the other odd-indexed bytes, meaning that when reading them, the same 6-bit address can be used for both of them and their outputs chained together to produce a 16 px line to write to one of the LED drivers. If the computer writes to the input latches while the `Memory write` pulse is happening, the address and data are both updated at the same time. If the address was just changed within a chip this wouldn't be a problem because the chip's WE# is edge-triggered. BUT when the address/data is updated (to a consecutive address) it switches from selecting one memory chip to the other, therefore ending the WE# pulse for one chip and enabling the WE# for the next one. Because the memory chip select logic (using the LSB of the byte address) has more propagation time then the data, the new data gets to the "old" memory chip faster then it can be deselected, causing it to be corrupted. The "new" memory chip is written to just fine.

```
{
  signal: [
    {name: "CLK", wave: "p|.......|"},
    {},
    {name: "Memory read", wave: "l|..h.l..|"},
    {name: "Memory output latch CLK", wave: "l|...hl..|"},
    {name: "Bit address", wave: "2222..2222", data: ["13", "14", "15", "0", "1", "2", "3", "4"]},
    {name: "Driver address", wave: "2..2......", data: ["7", "0"], node: "...a"},
    {name: "Counter enable", wave: "h|.l..h..|"},
    {name: "Counter CLK", wave: "p|..l.p..|"},
    {name: "Driver CLK enable", wave: "h|.l.nh..|"},
    {name: "Driver CLK", wave: "n|.l.nn..|"},
    {name: "Driver LE", wave: "l|.hl....|", node: "...b"},
    {},
    {name: "Memory write set data", wave: "l|....h.l|"},
    {name: "Memory write", wave: "l|.....pl|"},
  ],
  edge:['a~>b causes']
}
```

With the computer clock /16 and the display clock /256, with the extra move/write in the update loop (in `display_speed_test`), the glitch spacing is 9 rows on (on the same column).

A possible software solution is to seperately write all the even-indexed bytes then all the odd-indexed ones seperately so the chip being selected (by the address LSB) is (almost) never changed.

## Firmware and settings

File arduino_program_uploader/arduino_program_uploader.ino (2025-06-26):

/*  Arduino progrm to upload programs to the computer's program memory
 *  This program is responsible for the timing to send serial data into the chip address and data registers and to clock that into the memory chips
 *  Memory chips documentation: https://ww1.microchip.com/downloads/en/DeviceDoc/20005022C.pdf
 *  NOTE: The data sequence arrays have 16-bit entries even though the chip word size is 8bits, this is because there are two chips in parallel, so the command/data is repeated twice for each chip
 *  
 *  Procedure for uploading over serial:
 *  * Serial becomes available
 *  * RX two bytes (lower byte first) which represent the size of the program
 *  * Chip erase
 *  * TX 0b1000 0000 which means "chip erased"
 *  * Count for program size:
 *    * RX two bytes (lower byte first) which make up instruction, write it to chip
 *    * TX Progress as 1 byte, make sure to round down so 100% is only sent when actually done
 *  * TX 0b1000 0001 which means "done"
 */

#define pin_WE_inverted 2
#define pin_D_0_7 3
#define pin_D_8_15 4
#define pin_D_CLK 5
#define pin_A_0_7 6
#define pin_A_8_15 7
#define pin_A_CLK 8
#define pin_led 13

#define t_we_low 1
#define t_CE 110
#define t_BP 5
#define t_shift_reg_clock 1

#define POWER_16 65536
#define PROG_ARRAY_SIZE 600

static uint8_t CODE_CHIP_ERASED = 0b10000000;
static uint8_t CODE_WRITE_DONE = 0b10000001;

static uint16_t chip_erase_data_sequence[6] = {0xAAAA, 0x5555, 0x8080, 0xAAAA, 0x5555, 0x1010};
static uint16_t chip_erase_address_sequence[6] = {0x5555, 0x2AAA, 0x5555, 0x5555, 0x2AAA, 0x5555};

void recieve_and_upload_program() {
  // Wait for serial available
  while(Serial.available() == 0) {}
  // Receive two bytes for size
  uint16_t lower = (uint16_t)Serial.read();
  while(Serial.available() == 0) {}
  uint16_t upper = (uint16_t)Serial.read();
  uint16_t prog_size = lower | ((upper) << 8);
  Serial.write(prog_size);
  digitalWrite(pin_led, HIGH);
  //Serial.println("Program size: " + prog_size);
  // Erase chip
  chip_erase();
  Serial.write(CODE_CHIP_ERASED);
  //Serial.print("Loading program...");
  for(uint16_t i = 0; i < prog_size; i++) {
    // Receive and byte program
    uint16_t lower = (uint16_t)Serial.read();
    uint16_t upper = (uint16_t)Serial.read();
    uint16_t instruction = lower | ((upper) << 8);
    byte_program(i, instruction);
    // Send progress
    uint8_t progress = (uint8_t)(((uint32_t)(i+1))*100 / ((uint32_t)prog_size));
    Serial.write(progress);
  }
  //Serial.println(" Done");
  Serial.write(CODE_WRITE_DONE);
  digitalWrite(pin_led, LOW);
}

void upload_program(uint16_t program[PROG_ARRAY_SIZE], uint16_t start_address, uint16_t program_size, bool chip_erase_) {
  // Erase chip
  if(chip_erase_) {
    chip_erase();
  }
  // Upload program
  /*Serial.print("upload_program()\nInstruction 0: ");
  Serial.print(program[0], BIN);
  Serial.print(", Instruction 1: ");
  Serial.println(program[1], BIN);
  Serial.println();*/
  //Serial.print("Loading program...");
  for(uint16_t program_counter = 0; program_counter < program_size; program_counter++) {
    /*Serial.print("upload_program() write loop\nAddress: ");
    Serial.print(program_counter, BIN);
    Serial.print(", Instruction: ");
    Serial.println(program[program_counter], BIN);
    Serial.println();*/
    byte_program(program_counter + start_address, program[program_counter]);
  }
  //Serial.println(" Done");
}

void chip_erase() {
  //Serial.print("Erasing chips...");
  load_data_and_address(chip_erase_data_sequence, chip_erase_address_sequence, 6);
  // Delay (T-SCE = 100 millis)
  delay(t_CE);
  //Serial.println(" Done");
}

void byte_program(uint16_t address, uint16_t instruction) {
  // Prepare data and address sequences
  uint16_t data_sequence[6] = {0xAAAA, 0x5555, 0xA0A0, 0x0000, 0x0000, 0x0000};
  uint16_t address_sequence[6] = {0x5555, 0x2AAA, 0x5555, 0x0000, 0x0000, 0x0000};
  data_sequence[3] = instruction;
  address_sequence[3] = address;
  //Serial.println("byte_program()");
  /*Serial.print("Instruction: ");
  Serial.print(instruction, BIN);
  Serial.print(", Address: ");
  Serial.println(address, BIN);*/
  //Serial.println();
  // Load data
  load_data_and_address(data_sequence, address_sequence, 4);
  // Delay (T-BP = 20 micros)
  delay(t_BP);
}

void test_slow_single_instruction() {// move clk-counter-a gpio-write-a
  int prog_size = 2;
  uint16_t program[PROG_ARRAY_SIZE];
  program[0] = 0b1010101010101010;
  program[1] = 0b1100110011001100;
  /*Serial.print("Instruction 0: ");
  Serial.print(program[0], BIN);
  Serial.print(", Instruction 1: ");
  Serial.println(program[1], BIN);
  Serial.println();*/
  upload_program(program, prog_size, 0, true);
}

void load_data_and_address(uint16_t data_sequence[6], uint16_t address_sequence[6], uint8_t sequence_length) {
  for(uint8_t seq_i = 0; seq_i < sequence_length; seq_i++) {
    // Load into shift registers
    uint16_t curr_data = data_sequence[seq_i];
    uint16_t curr_address = address_sequence[seq_i];
    /*Serial.print("load_data_and_address()\nData: ");
    Serial.print(curr_data, BIN);
    Serial.print(", Address: ");
    Serial.println(curr_address, BIN);
    Serial.println();*/
    for(uint8_t bit_i = 7; bit_i != 255; bit_i--) {// Bits have to be shifted MSB first because that is the last stage of the shift registers
      digitalWrite(pin_D_0_7, bitRead(curr_data, bit_i));
      digitalWrite(pin_D_8_15, bitRead(curr_data, bit_i + 8));
      digitalWrite(pin_A_0_7, bitRead(curr_address, bit_i));
      digitalWrite(pin_A_8_15, bitRead(curr_address, bit_i + 8));
      delay(t_shift_reg_clock);
      digitalWrite(pin_D_CLK, HIGH);
      digitalWrite(pin_A_CLK, HIGH);
      delay(t_shift_reg_clock);
      digitalWrite(pin_D_CLK, LOW);
      digitalWrite(pin_A_CLK, LOW);
      delay(t_shift_reg_clock);
    }
    // WE
    digitalWrite(pin_WE_inverted, LOW);
    delay(t_we_low);
    digitalWrite(pin_WE_inverted, HIGH);
    delay(t_we_low);
  }
}

void test() {
  uint16_t program[PROG_ARRAY_SIZE];
  program[0] = 0b111000000000000;
  program[1] = 0b1001000011110001;
  program[2] = 0b111000000000000;
  program[3] = 0b1001000010110001;
  program[4] = 0b111000000000000;
  program[5] = 0b1001000001110001;
  program[6] = 0b111000000000000;
  program[7] = 0b1001000000110001;
  program[8] = 0b111000000000000;
  program[9] = 0b100110110110001;
  program[10] = 0b101000001000001;
  program[11] = 0b10;
  program[12] = 0b1001000000110001;
  program[13] = 0b111000000000000;
  program[14] = 0b1001000001110001;
  program[15] = 0b111000000000000;
  program[16] = 0b1001000010110001;
  program[17] = 0b111000000000000;
  program[18] = 0b1001000011110001;
  program[19] = 0b111000000000000;
  program[20] = 0b1001000000100001;
  program[21] = 0b111000000000000;
  program[22] = 0b1001000001100001;
  program[23] = 0b111000000000000;
  program[24] = 0b1001000010100001;
  program[25] = 0b111000000000000;
  program[26] = 0b1001000011100001;
  program[27] = 0b111000000000000;
  program[28] = 0b1001000000010001;
  program[29] = 0b111000000000000;
  program[30] = 0b1001000001010001;
  program[31] = 0b111000000000000;
  program[32] = 0b1001000010010001;
  program[33] = 0b111000000000000;
  program[34] = 0b1001000011010001;
  program[35] = 0b111000000000000;
  program[36] = 0b1001000000000001;
  program[37] = 0b111000000000000;
  program[38] = 0b1001000001000001;
  program[39] = 0b111000000000000;
  program[40] = 0b1001000010000001;
  program[41] = 0b111000000000000;
  program[42] = 0b1001000011000001;
  program[43] = 0b111000000000000;
  program[44] = 0b0;
  program[45] = 0b110;
  program[46] = 0b100000011100001;
  program[47] = 0b101000000010001;
  program[48] = 0b101;
  program[49] = 0b10000000000000;
  program[50] = 0b11000000010001;
  program[51] = 0b1001001001100000;
  program[52] = 0b1010100000000;
  program[53] = 0b1010100000000;
  program[54] = 0b100000110100001;
  program[55] = 0b101000000010001;
  program[56] = 0b101;
  program[57] = 0b10000000000000;
  program[58] = 0b1001000000010001;
  program[59] = 0b111001010000000;
  program[60] = 0b11000001110001;
  program[61] = 0b1001000001010001;
  program[62] = 0b111001001100000;
  program[63] = 0b11000001100001;
  program[64] = 0b1001000010010001;
  program[65] = 0b111001001100000;
  program[66] = 0b11000001010001;
  program[67] = 0b1001000011010001;
  program[68] = 0b111001001100000;
  program[69] = 0b11000001000001;
  program[70] = 0b1001000000000001;
  program[71] = 0b111001001100000;
  program[72] = 0b11000000110001;
  program[73] = 0b1001000001000001;
  program[74] = 0b111001001100000;
  program[75] = 0b11000000100001;
  program[76] = 0b1001000010000001;
  program[77] = 0b111001001100000;
  program[78] = 0b11000000010001;
  program[79] = 0b1001000011000001;
  program[80] = 0b111001001100000;
  program[81] = 0b10000000000000;
  program[82] = 0b1001000000110001;
  program[83] = 0b111001010000000;
  program[84] = 0b11000001110001;
  program[85] = 0b1001000001110001;
  program[86] = 0b111001001100000;
  program[87] = 0b11000001100001;
  program[88] = 0b1001000010110001;
  program[89] = 0b111001001100000;
  program[90] = 0b11000001010001;
  program[91] = 0b1001000011110001;
  program[92] = 0b111001001100000;
  program[93] = 0b11000001000001;
  program[94] = 0b1001000000100001;
  program[95] = 0b111001001100000;
  program[96] = 0b11000000110001;
  program[97] = 0b1001000001100001;
  program[98] = 0b111001001100000;
  program[99] = 0b11000000100001;
  program[100] = 0b1001000010100001;
  program[101] = 0b111001001100000;
  program[102] = 0b11000000010001;
  program[103] = 0b1001000011100001;
  program[104] = 0b111001001100000;
  program[105] = 0b110;
  program[106] = 0b10100000000000;
  program[107] = 0b11000001110001;
  program[108] = 0b110001001100000;
  program[109] = 0b100001101010001;
  program[110] = 0b101000001010001;
  program[111] = 0b11;
  program[112] = 0b100000011100001;
  program[113] = 0b101000000010001;
  program[114] = 0b101;
  program[115] = 0b1000011000000001;
  program[116] = 0b1000000001100001;
  program[117] = 0b1000001000100001;
  program[118] = 0b1000001000100001;
  program[119] = 0b1000110000000001;
  program[120] = 0b1000000001100001;
  program[121] = 0b1000001100000001;
  program[122] = 0b1000000001100001;
  program[123] = 0b1000001000100001;
  program[124] = 0b1000000001100001;
  program[125] = 0b1000010001000001;
  program[126] = 0b1000000001100001;
  program[127] = 0b1000011100000001;
  program[128] = 0b1000000000100001;
  program[129] = 0b1000011001000001;
  program[130] = 0b1000000000110001;
  program[131] = 0b100010010000001;
  program[132] = 0b101000001010001;
  program[133] = 0b10;
  program[134] = 0b100000011100001;
  program[135] = 0b101000000010001;
  program[136] = 0b101;
  program[137] = 0b1000011000110001;
  program[138] = 0b1000000000100001;
  program[139] = 0b1000001000100001;
  program[140] = 0b1000001000100001;
  program[141] = 0b1000110000000001;
  program[142] = 0b1000000001100001;
  program[143] = 0b1000001100000001;
  program[144] = 0b1000000001100001;
  program[145] = 0b1000001000100001;
  program[146] = 0b1000000001100001;
  program[147] = 0b1000110100000001;
  program[148] = 0b1000000000110001;
  program[149] = 0b1000011100000001;
  program[150] = 0b1000001000100001;
  program[151] = 0b1000011001000001;
  program[152] = 0b1000000000110001;
  program[153] = 0b110;
  program[154] = 0b1000000000001;
  program[155] = 0b1101111111110001;
  program[156] = 0b1001000100000000;
  program[157] = 0b1010100000000;
  program[158] = 0b1011100000000;
  program[159] = 0b1101111111100001;
  program[160] = 0b1000100000000;
  program[161] = 0b1101111111000001;
  program[162] = 0b10000100000000;
  program[163] = 0b11000001100001;
  program[164] = 0b10001001100000;
  program[165] = 0b11001111110001;
  program[166] = 0b1001001000000;
  program[167] = 0b1101111110110001;
  program[168] = 0b10000100000000;
  program[169] = 0b11000000110001;
  program[170] = 0b1001001000000;
  program[171] = 0b1101111110000001;
  program[172] = 0b10000100000000;
  program[173] = 0b1101111111100001;
  program[174] = 0b11000100000000;
  program[175] = 0b10001000000000;
  program[176] = 0b1101111111110001;
  program[177] = 0b11000100000000;
  program[178] = 0b1101111111100001;
  program[179] = 0b1100001010000000;
  program[180] = 0b1101111111110001;
  program[181] = 0b1100001010010000;
  program[182] = 0b1101111110010001;
  program[183] = 0b10000100000000;
  program[184] = 0b11000000000000;
  program[185] = 0b1001000000000;
  program[186] = 0b1101111101110001;
  program[187] = 0b110000100000000;
  program[188] = 0b100011101000001;
  program[189] = 0b101000001010001;
  program[190] = 0b11;
  program[191] = 0b100001001010001;
  program[192] = 0b101000001100001;
  program[193] = 0b101;
  program[194] = 0b100011101110001;
  program[195] = 0b101000001010001;
  program[196] = 0b10;
  program[197] = 0b100010111100001;
  program[198] = 0b101000001100001;
  program[199] = 0b101;
  program[200] = 0b1010000000000000;
  program[201] = 0b0;
  program[202] = 0b10000000000000;
  program[203] = 0b11000000010001;
  program[204] = 0b1001000000000;
  program[205] = 0b10001000000000;
  program[206] = 0b11000100000001;
  program[207] = 0b10001001110000;
  program[208] = 0b110001000100000;
  program[209] = 0b100010010100001;
  program[210] = 0b101000001010001;
  program[211] = 0b11;
  program[212] = 0b0;
  program[213] = 0b0;
  program[214] = 0b0;
  program[215] = 0b0;
  program[216] = 0b110;
  program[217] = 0b100000010110001;
  program[218] = 0b101000000010001;
  program[219] = 0b101;
  program[220] = 0b1000000000001;
  program[221] = 0b1000000000001;
  program[222] = 0b1010100000000;
  program[223] = 0b1011000000000;
  program[224] = 0b1011100000000;
  program[225] = 0b1101111111010001;
  program[226] = 0b1000100000000;
  program[227] = 0b1101111110100001;
  program[228] = 0b1000100000000;
  program[229] = 0b1000100000000;
  program[230] = 0b100001001010001;
  program[231] = 0b101000001100001;
  program[232] = 0b101;
  program[233] = 0b1010000000000000;
  program[234] = 0b1001000000000000;
  program[235] = 0b0;
  program[236] = 0b10000000000000;
  program[237] = 0b11000000010001;
  program[238] = 0b1001000000000;
  program[239] = 0b10001000000000;
  program[240] = 0b11000101000001;
  program[241] = 0b10001001110000;
  program[242] = 0b110001000100000;
  program[243] = 0b100100011010001;
  program[244] = 0b101000001010001;
  program[245] = 0b11;
  program[246] = 0b0;
  program[247] = 0b1000000000001;
  program[248] = 0b1101111111100001;
  program[249] = 0b10000100000000;
  program[250] = 0b11000000010001;
  program[251] = 0b10001000000000;
  program[252] = 0b1101111111110001;
  program[253] = 0b11000100000000;
  program[254] = 0b1101111111100001;
  program[255] = 0b1100001010000000;
  program[256] = 0b1101111111110001;
  program[257] = 0b1100001010010000;
  program[258] = 0b11000010100001;
  program[259] = 0b10001001110000;
  program[260] = 0b110001000100000;
  program[261] = 0b100100011010001;
  program[262] = 0b101000001010001;
  program[263] = 0b11;
  program[264] = 0b0;
  program[265] = 0b0;
  program[266] = 0b110;
  program[267] = 0b100000100010001;
  program[268] = 0b101000000010001;
  program[269] = 0b101;
  program[270] = 0b1001000100000001;
  program[271] = 0b10010100000000;
  program[272] = 0b11111111110001;
  program[273] = 0b10001000000000;
  program[274] = 0b11000000010001;
  program[275] = 0b110001001100000;
  program[276] = 0b1000000000001;
  program[277] = 0b100110010010001;
  program[278] = 0b101000001010001;
  program[279] = 0b11;
  program[280] = 0b0;
  program[281] = 0b1001010000000;
  program[282] = 0b10010100000000;
  program[283] = 0b11000000010001;
  program[284] = 0b110001001100000;
  program[285] = 0b1000000000001;
  program[286] = 0b100110100100001;
  program[287] = 0b101000001010001;
  program[288] = 0b11;
  program[289] = 0b0;
  program[290] = 0b1001010000000;
  program[291] = 0b1101111111100001;
  program[292] = 0b10000100000000;
  program[293] = 0b11000001100001;
  program[294] = 0b1001000000000;
  program[295] = 0b10000100000000;
  program[296] = 0b11000001010001;
  program[297] = 0b1001000000000;
  program[298] = 0b1101111111000001;
  program[299] = 0b1000100000000;
  program[300] = 0b1000100000000;
  program[301] = 0b1101111111100001;
  program[302] = 0b10000100000000;
  program[303] = 0b11000001000001;
  program[304] = 0b1001001100000;
  program[305] = 0b11000000100001;
  program[306] = 0b10001001100000;
  program[307] = 0b11000000000000;
  program[308] = 0b10001000000000;
  program[309] = 0b1101111111110001;
  program[310] = 0b11000100000000;
  program[311] = 0b100000010110001;
  program[312] = 0b101000000010001;
  program[313] = 0b101;
  program[314] = 0b1001001000000000;
  program[315] = 0b1010000000000;
  program[316] = 0b1101111111010001;
  program[317] = 0b1000100000000;
  program[318] = 0b1000100000000;
  program[319] = 0b100001001010001;
  program[320] = 0b101000001100001;
  program[321] = 0b101;
  program[322] = 0b10000000000000;
  program[323] = 0b11000000010001;
  program[324] = 0b1001000000000;
  program[325] = 0b10001000000000;
  program[326] = 0b1101111111010001;
  program[327] = 0b11000100000000;
  program[328] = 0b110001001110000;
  program[329] = 0b100000000110001;
  program[330] = 0b101000001100001;
  program[331] = 0b11;
  program[332] = 0b11000101000001;
  program[333] = 0b110001001110000;
  program[334] = 0b100000000110001;
  program[335] = 0b101000001100001;
  program[336] = 0b11;
  program[337] = 0b100110111000001;
  program[338] = 0b101000001010001;
  program[339] = 0b10;
  program[340] = 0b0;
  program[341] = 0b1101111110110001;
  program[342] = 0b1000100000000;
  program[343] = 0b1101111111100001;
  program[344] = 0b10000100000000;
  program[345] = 0b11000000010001;
  program[346] = 0b10001000000000;
  program[347] = 0b1101111111110001;
  program[348] = 0b11000100000000;
  program[349] = 0b1101111111100001;
  program[350] = 0b1100001010000000;
  program[351] = 0b1101111111110001;
  program[352] = 0b1100001010010000;
  program[353] = 0b1101111111000001;
  program[354] = 0b11000100000000;
  program[355] = 0b110001001110000;
  program[356] = 0b100000111100001;
  program[357] = 0b101000001100001;
  program[358] = 0b11;
  program[359] = 0b11000010100001;
  program[360] = 0b110001001110000;
  program[361] = 0b100000111100001;
  program[362] = 0b101000001100001;
  program[363] = 0b11;
  program[364] = 0b100110111000001;
  program[365] = 0b101000001010001;
  program[366] = 0b10;
  program[367] = 0b0;
  program[368] = 0b0;
  program[369] = 0b0;
  program[370] = 0b0;
  program[371] = 0b0;
  program[372] = 0b0;
  program[373] = 0b110;
  program[374] = 0b1101111111100001;
  program[375] = 0b10000100000000;
  program[376] = 0b11000000010001;
  program[377] = 0b10001000000000;
  program[378] = 0b11000001010001;
  program[379] = 0b10001001100000;
  program[380] = 0b11000111110001;
  program[381] = 0b1001001000000;
  program[382] = 0b1101111111010001;
  program[383] = 0b10000100000000;
  program[384] = 0b11000000010001;
  program[385] = 0b10001000000000;
  program[386] = 0b11000001110001;
  program[387] = 0b1001001000000;
  program[388] = 0b10000100000000;
  program[389] = 0b10001000100000;
  program[390] = 0b11000111110001;
  program[391] = 0b10001000000000;
  program[392] = 0b11000000100001;
  program[393] = 0b10001001100000;
  program[394] = 0b11111111000001;
  program[395] = 0b1001001000000;
  program[396] = 0b10000100000000;
  program[397] = 0b1101111111110001;
  program[398] = 0b11000100000000;
  program[399] = 0b1001001000000000;
  program[400] = 0b1010000000000001;
  program[401] = 0b1101111111100001;
  program[402] = 0b10000100000000;
  program[403] = 0b10001000100000;
  program[404] = 0b11000010010001;
  program[405] = 0b11001000000000;
  program[406] = 0b10010000000000;
  program[407] = 0b10001001100000;
  program[408] = 0b1101111110100001;
  program[409] = 0b110000100000000;
  program[410] = 0b100010100010001;
  program[411] = 0b101000001100001;
  program[412] = 0b11;
  program[413] = 0b11111111100001;
  program[414] = 0b1001001000000;
  program[415] = 0b100010100110001;
  program[416] = 0b101000001100001;
  program[417] = 0b10;
  program[418] = 0b11000000010001;
  program[419] = 0b1001000110000;
  program[420] = 0b1101111111010001;
  program[421] = 0b11000100000000;
  program[422] = 0b10000000000000;
  program[423] = 0b111001001100000;
  program[424] = 0b0;
  program[425] = 0b0;
  program[426] = 0b0;
  program[427] = 0b0;
  program[428] = 0b0;
  program[429] = 0b0;
  program[430] = 0b110;
  program[431] = 0b1101111111100001;
  program[432] = 0b10000100000000;
  program[433] = 0b11000000010001;
  program[434] = 0b10001000000000;
  program[435] = 0b11000001010001;
  program[436] = 0b10001001100000;
  program[437] = 0b11000111110001;
  program[438] = 0b1001001000000;
  program[439] = 0b1101111111010001;
  program[440] = 0b10000100000000;
  program[441] = 0b11000000010001;
  program[442] = 0b10001000000000;
  program[443] = 0b11000001110001;
  program[444] = 0b1001001000000;
  program[445] = 0b10000100000000;
  program[446] = 0b10001000100000;
  program[447] = 0b11000111110001;
  program[448] = 0b10001000000000;
  program[449] = 0b11000000100001;
  program[450] = 0b10001001100000;
  program[451] = 0b11111111000001;
  program[452] = 0b1001001000000;
  program[453] = 0b10000100000000;
  program[454] = 0b1101111111110001;
  program[455] = 0b11000100000000;
  program[456] = 0b1001001000000000;
  program[457] = 0b1010000000000001;
  program[458] = 0b1101111111100001;
  program[459] = 0b10000100000000;
  program[460] = 0b10001000100000;
  program[461] = 0b11000010010001;
  program[462] = 0b11001000000000;
  program[463] = 0b10010000000000;
  program[464] = 0b1001001100000;
  program[465] = 0b1101111110010001;
  program[466] = 0b10000100000000;
  program[467] = 0b11000000010001;
  program[468] = 0b10001001000000;
  program[469] = 0b11000000000000;
  program[470] = 0b1001000110000;
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
void loop() {
  
}

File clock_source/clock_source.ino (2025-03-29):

bool state = false;
void setup() {
  // put your setup code here, to run once:
  pinMode(8, OUTPUT);
}

void digitalWriteModified(uint8_t pin, uint8_t val)
{
	//uint8_t timer = digitalPinToTimer(pin);
	uint8_t bit = digitalPinToBitMask(pin);
	uint8_t port = digitalPinToPort(pin);
	volatile uint8_t *out;

	//if (port == NOT_A_PIN) return;

	// If the pin that support PWM output, we need to turn it off
	// before doing a digital write.
	//if (timer != NOT_ON_TIMER) turnOffPWM(timer);

	out = portOutputRegister(port);

	uint8_t oldSREG = SREG;
	cli();

	if (val == LOW) {
		*out &= ~bit;
	} else {
		*out |= bit;
	}

	SREG = oldSREG;
}

void loop() {
  // put your main code here, to run repeatedly:
  //digitalWrite(8, state);
  /*if(state) {
    PORTB = B00000001;//PORTB | 0b00000001;
  }
  else {
    PORTB = B00000000;//PORTB & 0b11111110;
  }
  state = !state;*/
  //PORTB = B00000001;
  //PORTB = B00000000;
  PORTB = (!PORTB) & B00000001;
}

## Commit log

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2024-04-04 Clarified some details and swapped PUSH instruction with WRITE
    [mod.rs, tests.rs]
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2024-05-14 Fixed emulator and examples
    [mod.rs, tests.rs]
2024-05-23 Started using KiCad
    [cad.kicad_pcb, cad.kicad_sch]
2024-05-25 CAD stuff
    [cad.kicad_sch]
2024-05-26 I love KiCad
    [cad.kicad_sch]
2024-05-29 timing stuff and CAD
    [cad.kicad_sch, clock.kicad_pcb, clock.kicad_sch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]
2024-05-31 Improved timing
    [stack_controller.kicad_sch]
2024-06-01 Possibly final design of stack controller
    [stack_controller.kicad_pcb, stack_controller.kicad_sch]
2024-06-05 kicad stuff and timing
    [bus.kicad_pcb, bus.kicad_sch, stack_controller.kicad_pcb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]
2024-06-07 Finished schematic for motherboard
    [bus.kicad_pcb, bus.kicad_sch, freerouting.dsn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]
2024-06-11 Work on control unit
    [control_unit.kicad_pcb, control_unit.kicad_sch]
2024-06-12 Work on call stack and instruction sequence timing
    [call_stack.kicad_pcb, call_stack.kicad_sch, control_unit.kicad_sch]
2024-06-13 Completed design for call stack
    [call_stack.kicad_sch]
2024-06-24 Finished main PCB design
    [bus.kicad_pcb, freerouting.dsn, temp-freerouting.dsn]
2024-06-29 Working on clock
    [bus.kicad_pcb, clock.kicad_sch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]
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2024-07-11 Increased clock PCB clearances
    [breakout_32_DIP_0_6_inch.kicad_pcb, bus.kicad_sch, clock.kicad_pcb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]
2024-07-12 Added pulldown resistors to clock module inputs
    [clock.kicad_pcb, clock.kicad_sch]
2024-07-22 Working on control unit schematic
    [control_unit_central_timing.kicad_sch]
2024-07-22 Finished central timing schematic & created progress table
    [control_unit_central_timing.kicad_pcb, control_unit_central_timing.kicad_sch]
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2024-07-26 Done w/ ALU schematic
    [ALU.kicad_sch, bus.kicad_pcb, bus.kicad_sch]
2024-07-26 Updating parts spreadsheet (not done)
    [ALU.kicad_pcb, control_unit_central_timing.kicad_pcb, control_unit_central_timing.kicad_sch]
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2024-08-03 Added pullup resistors to control unit memory address
    [control_unit.kicad_pcb, control_unit.kicad_sch]
2024-08-04 Working on GPRAM schematic
    [control_unit.kicad_pcb, control_unit.kicad_sch, gpram.kicad_sch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]
2024-08-05 Finished IO controller schematic
    [ALU.kicad_pcb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]
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2024-08-11 Finished central timing PCB
    [control_unit_central_timing-B_Cu.gbr, control_unit_central_timing-B_Mask.gbr, control_unit_central_timing-B_Paste.gbr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]
2024-08-11 Finished call stack schematic
    [call_stack.kicad_sch, control_unit.kicad_pcb, control_unit.kicad_sch]
2024-08-13 Finished prog memory timing diagrams
    [call_stack.kicad_pcb, control_unit.kicad_pcb, control_unit.kicad_sch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]
2024-08-19 Finished some more PCBs and uploaded to JLCPCB
    [bom.csv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]
2024-08-20 Almost done with prog mem schematic
    [ALU.kicad_pcb, bom.csv, designators.csv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]
2024-08-20 Finished prog mem schematic
    [prog_mem.kicad_sch]
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2024-12-12 Added compiler functionality to deal with stack offset
    [gpram.kicad_pcb, gpram.kicad_sch, led_matrix.kicad_pcb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]
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2024-12-16 Sick new LED block footprints
    [freerouting.dsn, led_matrix.kicad_pcb, led_matrix.kicad_sch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]
2024-12-22 Almost done with led matrix schematic
    [led_matrix.kicad_pcb, led_matrix.kicad_sch]
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2024-12-23 LED matrix PCB done
    [bom.csv, designators.csv, led_matrix.kicad_pcb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]
2024-12-23 Fixed prog mem and updated PCB
    [prog_mem.kicad_pcb, prog_mem.kicad_sch]
2024-12-23 Fixed clock board
    [bom.csv, clock.kicad_pcb, clock.kicad_sch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]
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2024-12-31 Added failsafe to LED matrix and some other stuff
    [led_matrix.kicad_pcb, led_matrix.kicad_sch]
2024-12-31 Added connector on IO controller to support display
    [bom.csv, designators.csv, io_controller.kicad_pcb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]
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2025-01-02 Fixed led matrix board
    [led_matrix.kicad_pcb, led_matrix.kicad_sch]
2025-01-03 Fixed led matrix controller
    [led_matrix_controller.kicad_pcb, led_matrix_controller.kicad_sch]
2025-01-07 Added new led matrix board for the 8x8 displays
    [bom.csv, designators.csv, do_not_use_led_matrix.kicad_sch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]
2025-01-09 Tetris program draw-shape and init-next-shape-from-storage functions work
    [bom.csv, designators.csv, led_matrix.kicad_pcb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]
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2025-02-19 Point test and work on optimizing tetris
    [led_matrix_controller.kicad_sch]
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2025-03-29 Control panel almost done
    [control_panel.kicad_pcb, control_panel.kicad_sch]
2025-04-04 Improved control panel and fixed music program
    [control_panel.kicad_pcb, control_panel.kicad_sch]
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2025-05-21 Circuit replacement animation works
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2025-05-24 Fixed larger circuit animation and making slides
2025-12-05 Working on vector controller
    [godzilla.kicad_pcb, godzilla.kicad_sch, vector_digital_controller.kicad_pcb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]
2025-12-08 Fixed vector timing for stupid DACs
    [bom.csv, designators.csv, godzilla.kicad_pcb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]
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2025-12-27 Progress on vector thingy
    [vector_digital_controller.kicad_pcb, vector_digital_controller.kicad_sch]
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2026-01-06 About to change bus loading
    [freerouting.dsn, vector_digital_controller.kicad_pcb]
2026-01-07 Bus loading fixed
    [vector_digital_controller.kicad_sch]
2026-01-08 Vector thingy almost completely verified except math and DAC stuff
    [vector_digital_controller.kicad_pcb, vector_digital_controller.kicad_sch]
2026-01-10 Vector graphics board finished
    [freerouting.dsn, vector_digital_controller.kicad_pcb, vector_digital_controller.kicad_sch]
2026-01-15 Moved rusty logic circuits into this repo
    [ALU.kicad_pcb, ALU.kicad_sch, bom.csv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]
2026-01-23 Added V2 into this repo
    [ALU.kicad_pcb, ALU.kicad_sch, bom.csv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]
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2026-03-03 About to fix same device TX and RX problem
2026-03-03 Probably fixed same device tx rx problem
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2026-03-15 Fixed interrupts and work on emulator for v2
    [mod.rs, tests.rs]
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2026-03-25 Debug figured out and work on ctrl unit main
    [call_stack.kicad_sch, control_unit.kicad_sch, main_sequencer_v2.kicad_sch]
2026-03-25 Control unit main schematic verified
    [control_unit.kicad_sch]
2026-03-26 Bus sequencer kicad verified
    [bus.kicad_sch, bus_sequencer_v2.kicad_pcb, bus_sequencer_v2.kicad_sch]
2026-03-28 Work mostly on bus
    [ALU.kicad_sch, bus.kicad_sch, gpram.kicad_sch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]
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2026-03-30 Bus and starter verified
    [bus.kicad_sch, starter_v2.kicad_pcb, starter_v2.kicad_sch]
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2026-04-09 Stack data v2 verified
    [bom.csv, designators.csv, positions.csv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]
